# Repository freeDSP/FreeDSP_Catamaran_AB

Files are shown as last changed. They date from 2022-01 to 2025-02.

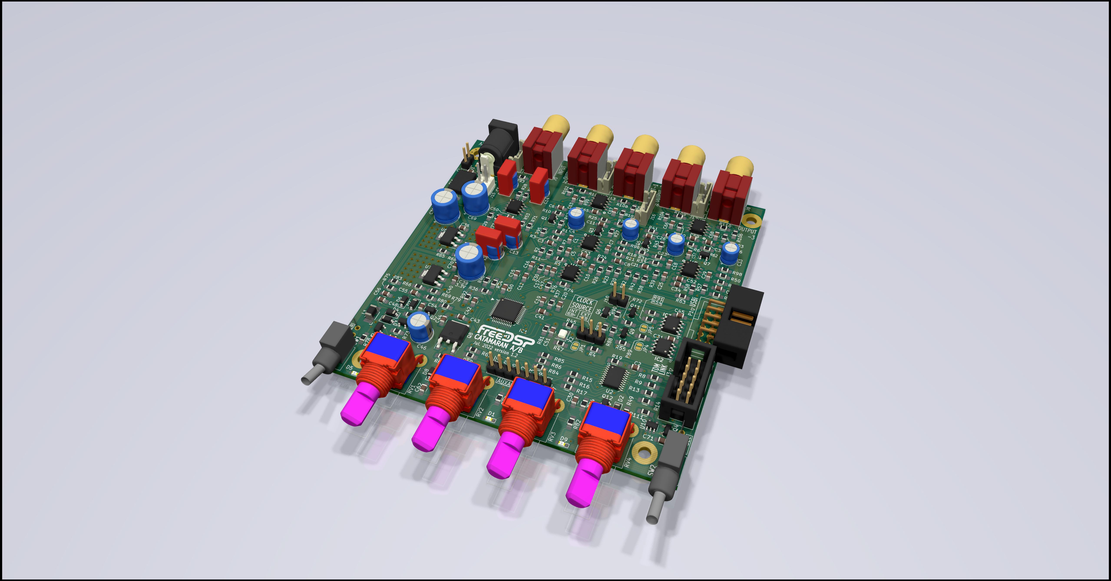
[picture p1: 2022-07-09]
Photo/FreeDSP_Catamaran_1v2_ParseRendering.jpg

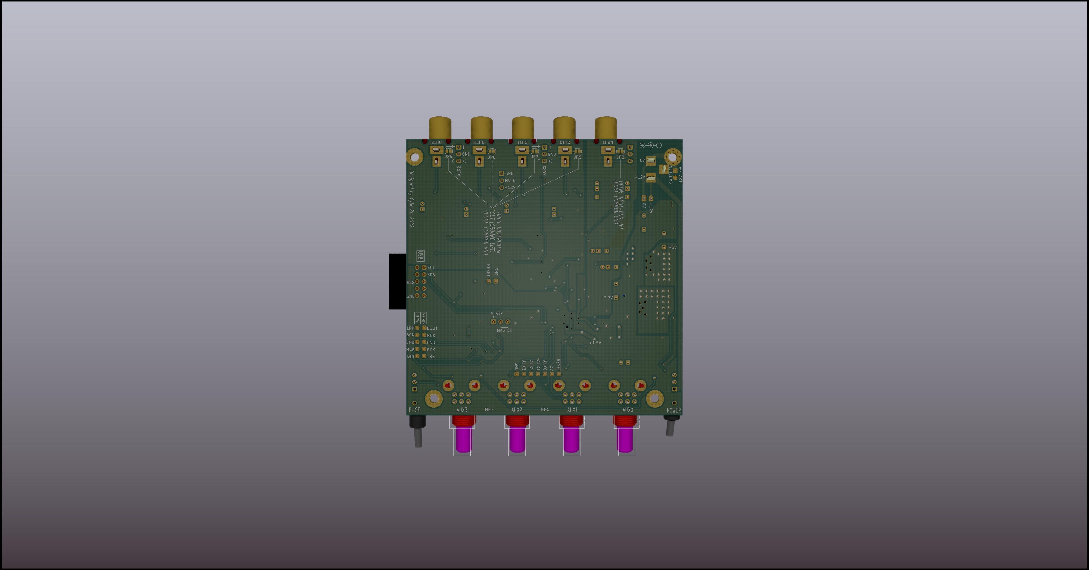
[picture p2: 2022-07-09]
Photo/FreeDSP_Catamaran_1v2_BottomRendering.jpg

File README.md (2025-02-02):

# FreeDSP_Catamaran_AB
A dual mono construction Concept Differential ADC 1 in 4 out ADAU1701 board. Extreme High performance (ADC to DAC Overall Distortion 0.00087%) differential A/D Conversion, differential RCA-pin Outputs, fs=96kHz, 8 slots TDM-Interlink across the boards.

Features:

- 1in 4 out RCA jacks on each PCB (2 boards requires for stereo use)
- High-performance differential monaural ADAU1701 ADC circuit
- GND lift-able Differntial RCA-pin Input curcuit
- GND lift-able Differential RCA-pin Output circuit
- Mains Power Switch
- Power-ON/OFF/Reboot Anti-Pop Audio Mute
- LED Power Indicator
- MP1/MP7 controlled LED Indicators
- A/B Program Select switch with Auto-Reboot feature
- Selectable DSP reboot Dual-EEPROMs
- Rotary Pots for AUXADC 0-3
- interlink header for AUXADC control voltage 0-3 and Reset
- Common-mode Choke filtered Power Supply Input
- 0805(2.0mm x 1.25mm) SMD Resistors & Capacitors
- Prepare for the through-hole Ele-Caps on the Audio Path
- Unity Gain Analog Audio Input and Output (2V RMS)
- Absolute Phase transparent. (No need to invert Output Phase)
- Buffered TDM Interlink I/O Header (with Enable control)
- JST-EH Connectors for Optional XLR output driver board.

PCBA file package included in JLPCB_OrderFiles. You can order SMT and Boards. (https://jlcpcb.com/) 

A Wiki Page(https://github.com/freeDSP/FreeDSP_Catamaran_AB/wiki) of this project

Discussion forum thread (https://www.diyaudio.com/community/threads/freedsp-catamaran-a-b.381417/)

Project web page: (Direct Link) https://cyberpithilo.web.fc2.com/audio/freedsp/index.html

Project web page: (Yandex Machine Translation) https://translate.yandex.com/translate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

Project web page: (Google Machine Translation) https://cyberpithilo-web-fc2-com.translate.goog/audio/freedsp/catamaran_main.html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

# License
This work and all other materials under https://github.com/freeDSP are licensed under a Creative Commons Attribution Share-Alike 4.0 license. This allows for both personal and commercial derivative works, as long as they credit freeDSP and release their designs under the same license.

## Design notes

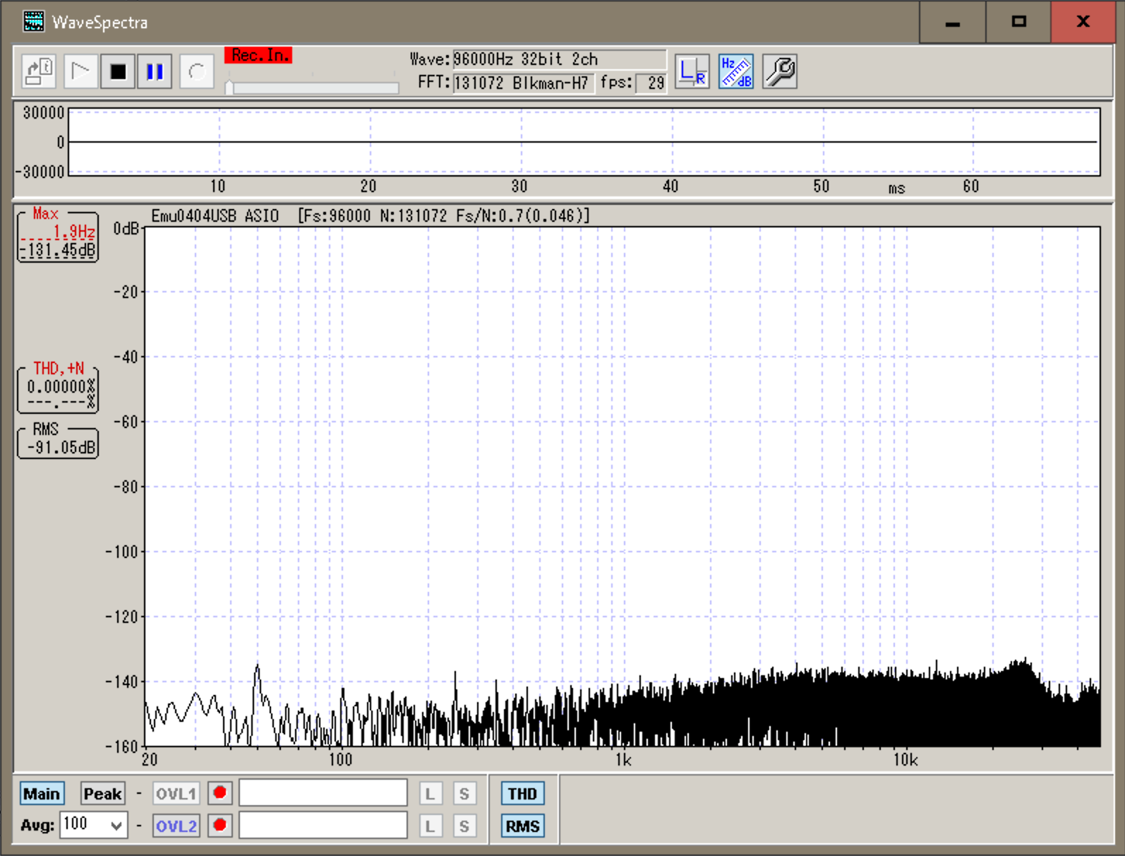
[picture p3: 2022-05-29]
Photo/RemainNoiseSPectrum.png

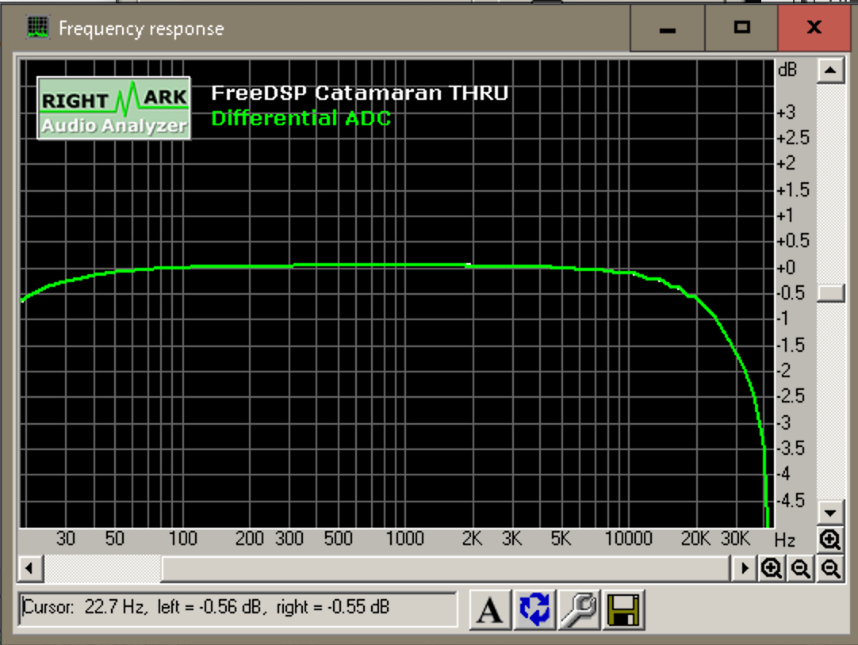
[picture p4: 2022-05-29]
Photo/Frequency Response(96kHz).png

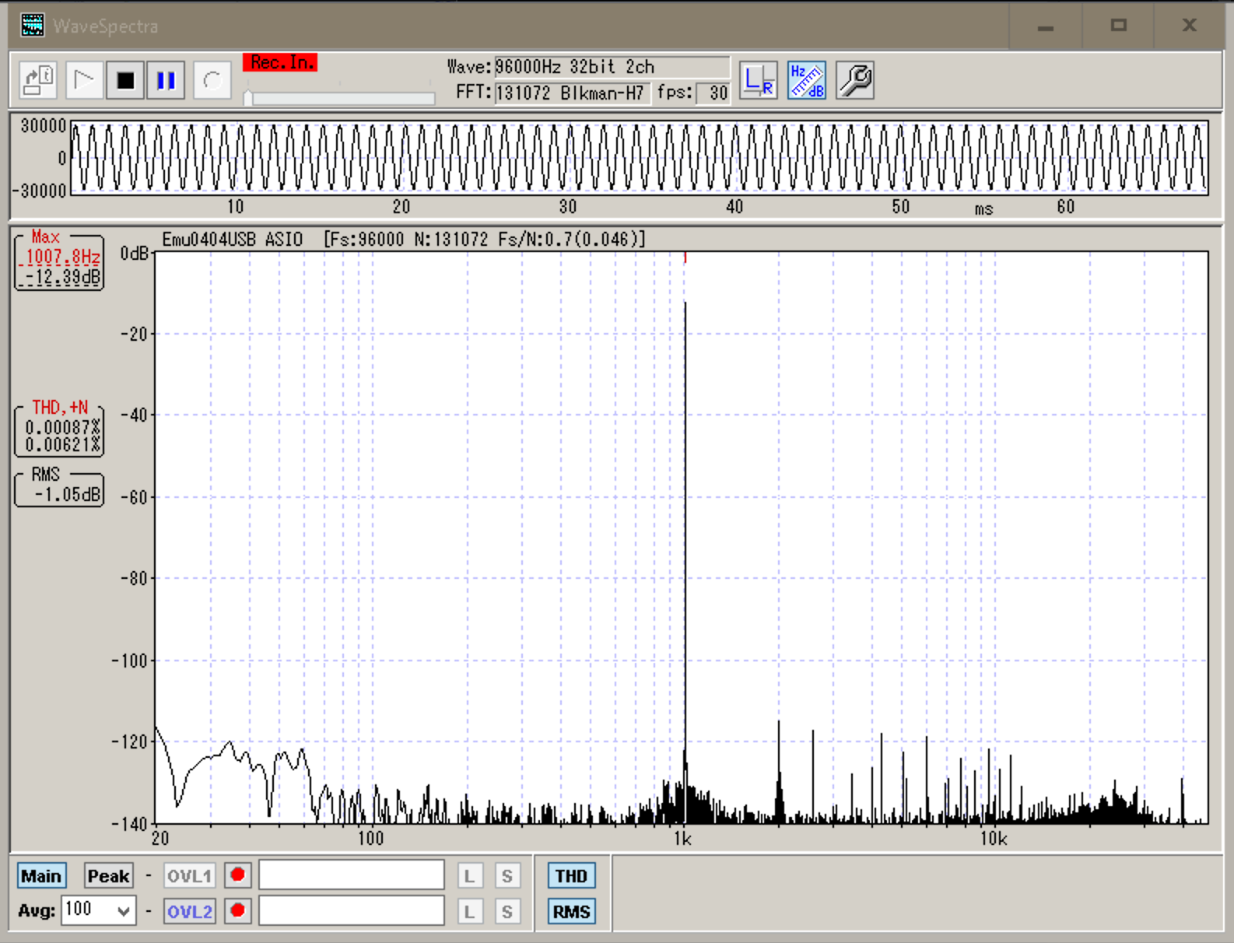
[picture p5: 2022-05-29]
Photo/0v21_Differential-ADC_THD.png

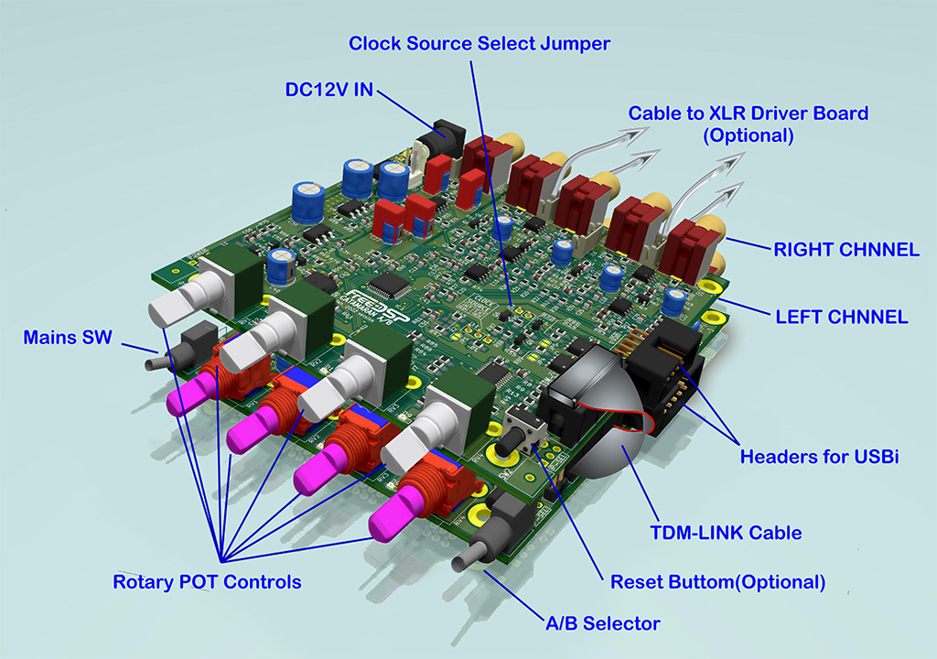
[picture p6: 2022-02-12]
Photo/FreeDSP_CatamaranStackedImage.jpg

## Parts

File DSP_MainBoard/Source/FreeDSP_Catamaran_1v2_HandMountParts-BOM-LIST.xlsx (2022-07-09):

Comment | Designator | Footprint | JLCPCB Part #（optional） | QTY for Stereo Link | COMMENT | SHOP URL
100u/16V | C46 | Capacitor_THT:CP_Radial_D6.3mm_P2.50mm |  | 2 | OS-CON | https://akizukidenshi.com/catalog/g/gP-08290/
10u/16V | C23 | Capacitor_THT:CP_Radial_D5.0mm_P2.00mm |  | 8 | Elecaps for Audio | https://akizukidenshi.com/catalog/g/gP-04621/
10u/16V | C33 | Capacitor_THT:CP_Radial_D5.0mm_P2.00mm
10u/16V | C4 | Capacitor_THT:CP_Radial_D5.0mm_P2.00mm
10u/16V | C9 | Capacitor_THT:CP_Radial_D5.0mm_P2.00mm
2.2uF/16 | C14 | Myfootprints:CP_Combo_D5.0mm_P2-5mm |  | 4 | Film or Elecaps for Audio
2.2uF/16 | C58 | Myfootprints:CP_Combo_D5.0mm_P2-5mm
220u | C38 | Capacitor_THT:CP_Radial_D8.0mm_P5.00mm |  | 6 | OS-CON | https://akizukidenshi.com/catalog/g/gP-08291/
220u | C39 | Capacitor_THT:CP_Radial_D8.0mm_P5.00mm
220u/16V | C69 | Capacitor_THT:CP_Radial_D8.0mm_P5.00mm
2MS1T1B4M7QES | SW1 | Myfootprints:2MS1T1B4M7QES |  | 3pcs Total or 2pcs for Linked | POWER SWITCH | https://akizukidenshi.com/catalog/g/gP-13796/
2MS1T1B4M7QES | SW2 | Myfootprints:2MS1T1B4M7QES |  |  | PROGRAM SELECT SWITCH | https://akizukidenshi.com/catalog/g/gP-13796/
47uF/6.3 | C13 | Myfootprints:CP_Combo_D5.0mm_P2-5mm |  | 4 | Elecaps for Audio
47uF/6.3 | C22 | Myfootprints:CP_Combo_D5.0mm_P2-5mm
ALPS_RK09_B10K | RV1 | Potentiometers:Potentiometer_Alps_RK09L_Double_Vertical |  | 4pcs Total or 8pcs | 4pcs if use J7 interlink 8pcs for separate control | https://akizukidenshi.com/catalog/g/gP-12576/
ALPS_RK09_B10K | RV2 | Potentiometers:Potentiometer_Alps_RK09L_Double_Vertical
ALPS_RK09_B10K | RV3 | Potentiometers:Potentiometer_Alps_RK09L_Double_Vertical
ALPS_RK09_B10K | RV4 | Potentiometers:Potentiometer_Alps_RK09L_Double_Vertical
B3B-EH | J12 | Connector_JST:JST_XH_B3B-XH-AM_1x03_P2.50mm_Vertical |  | Optional for XLR Board | Optional for input/output for XLR Connector Board | https://www.digikey.jp/ja/products/detail/jst-sales-america-inc/B3B-EH-A-LF-SN/926521
B3B-EH | J13 | Connector_JST:JST_XH_B3B-XH-AM_1x03_P2.50mm_Vertical
B3B-EH | J14 | Connector_JST:JST_XH_B3B-XH-AM_1x03_P2.50mm_Vertical
Conn_01x02 | J1 | Connector_PinHeader_2.54mm:PinHeader_1x02_P2.54mm_Vertical |  | Long Pin-Header & Socket for Stacking | Interlink for DC 12V Supply Power
Conn_01x02 | J10 | Connector_PinHeader_2.54mm:PinHeader_1x02_P2.54mm_Vertical |  |  | Interlink for synchroniced RESET
B3B-EH | J16 | Connector_PinHeader_2.54mm:PinHeader_1x03_P2.54mm_Vertical |  | JST EH BasePost | Optional for XLR Board Power & Reset
Conn_01x07_Male | J7 | Connector_PinHeader_2.54mm:PinHeader_1x07_P2.54mm_Vertical |  | Socket for Stacking | Optional for votage Interlink Potentiometer and Reset
Conn_02x5_Odd_Even | J3 | Connector_IDC:IDC-Header_2x05_P2.54mm_Vertical |  | 2 | Plus Reverse connected 10P IDC cable required for Stereo Link | https://akizukidenshi.com/catalog/g/gC-12664/
Conn_Power_2.1mm | J9 | Connect:BARREL_JACK |  | 1pce total | 5.5mm Sleeve 2.1mm Center-Pin
Conn_RCA | J2 | MyJacks:RJ-2410N |  | RED & WHITE 5pcs each | REDx5pcs and WHITEx5pcs | https://akizukidenshi.com/catalog/g/gC-16498/
Conn_RCA | J4 | MyJacks:RJ-2410N |  |  |  | https://akizukidenshi.com/catalog/g/gC-16497/
Conn_RCA | J5 | MyJacks:RJ-2410N |  |  |  | https://www.digikey.jp/ja/products/detail/kycon-inc/KLPX-0848A-2-R/9990119
Conn_RCA | J6 | MyJacks:RJ-2410N |  |  |  | https://www.digikey.jp/ja/products/detail/kycon-inc/KLPX-0848A-2-W/9990120
Conn_RCA | J8 | MyJacks:RJ-2410N
HeaderPin_01x03 | J11 | Connector_PinHeader_2.54mm:PinHeader_1x03_P2.54mm_Vertical |  | 2 | JUMPER-PIN Requred for each
MIL-10P_Angle | P1 | Connector_IDC:IDC-Header_2x05_P2.54mm_Right Angle |  | 2 | for USBi | https://akizukidenshi.com/catalog/g/gC-13178/
Molex 1718563002 | J15 | Connector_Molex:Molex_KK-254_AE-6410-02A_1x02_P2.54mm_Vertical |  | Optional | for external power supply
NOP | R59 | Resistors_SMD:R_0805_HandSoldering |  | 0 | Not need
24AA256(or CAT24M01WI-GT3) | IC2 | Housings_SOIC:SOIC-8_3.9x4.9mm_Pitch1.27mm |  | 2 | I2C EEPROM | https://akizukidenshi.com/catalog/g/gI-10492/
24AA256(or CAT24M01WI-GT3) | IC3 | Housings_SOIC:SOIC-8_3.9x4.9mm_Pitch1.27mm |  | 2 | I2C EEPROM | https://akizukidenshi.com/catalog/g/gI-10492/

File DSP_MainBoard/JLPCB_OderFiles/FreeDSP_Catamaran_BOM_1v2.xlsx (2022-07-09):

Comment | Designator | Footprint | JLCPCB Part #（optional）
0R | R68 | Resistors_SMD:R_0805_HandSoldering | C17477
0R | R69 | Resistors_SMD:R_0805_HandSoldering | C17477
0R | R76 | Resistors_SMD:R_0805_HandSoldering | C17477
0R | R80 | Resistors_SMD:R_0805_HandSoldering | C17477
0R | R92 | Resistors_SMD:R_0805_HandSoldering | C17477
1000PF | C21 | Capacitors_SMD:C_0805_HandSoldering | C343010
1000PF | C3 | Capacitors_SMD:C_0805_HandSoldering | C343010
1000PF | C32 | Capacitors_SMD:C_0805_HandSoldering | C343010
1000PF | C8 | Capacitors_SMD:C_0805_HandSoldering | C343010
100k | R67 | Resistors_SMD:R_0805_HandSoldering | C149504
100k | R74 | Resistors_SMD:R_0805_HandSoldering | C149504
100n | C17 | Capacitors_SMD:C_0805_HandSoldering | C49678
100n | C2 | Capacitors_SMD:C_0805_HandSoldering | C49678
100n | C24 | Capacitors_SMD:C_0805_HandSoldering | C49678
100n | C31 | Capacitors_SMD:C_0805_HandSoldering | C49678
100n | C37 | Capacitors_SMD:C_0805_HandSoldering | C49678
100n | C42 | Capacitors_SMD:C_0805_HandSoldering | C49678
100n | C44 | Capacitors_SMD:C_0805_HandSoldering | C49678
100n | C45 | Capacitors_SMD:C_0805_HandSoldering | C49678
100n | C50 | Capacitors_SMD:C_0805_HandSoldering | C49678
100n | C51 | Capacitors_SMD:C_0805_HandSoldering | C49678
100n | C52 | Capacitors_SMD:C_0805_HandSoldering | C49678
100n | C53 | Capacitors_SMD:C_0805_HandSoldering | C49678
100n | C59 | Capacitors_SMD:C_0805_HandSoldering | C49678
100n | C60 | Capacitors_SMD:C_0805_HandSoldering | C49678
100n | C61 | Capacitors_SMD:C_0805_HandSoldering | C49678
100n | C65 | Capacitors_SMD:C_0805_HandSoldering | C49678
100n | C70 | Capacitors_SMD:C_0805_HandSoldering | C49678
100n | C71 | Capacitors_SMD:C_0805_HandSoldering | C49678
100R | R13 | Resistors_SMD:R_0805_HandSoldering | C17408
100R | R14 | Resistors_SMD:R_0805_HandSoldering | C17408
100R | R15 | Resistors_SMD:R_0805_HandSoldering | C17408
100R | R16 | Resistors_SMD:R_0805_HandSoldering | C17408
100R | R17 | Resistors_SMD:R_0805_HandSoldering | C17408
100R | R4 | Resistors_SMD:R_0805_HandSoldering | C17408
100R | R45 | Resistors_SMD:R_0805_HandSoldering | C17408
100R | R8 | Resistors_SMD:R_0805_HandSoldering | C17408
100R | R81 | Resistors_SMD:R_0805_HandSoldering | C17408
100R | R84 | Resistors_SMD:R_0805_HandSoldering | C17408
100R | R85 | Resistors_SMD:R_0805_HandSoldering | C17408
100R | R86 | Resistors_SMD:R_0805_HandSoldering | C17408
100R | R9 | Resistors_SMD:R_0805_HandSoldering | C17408
100R | R93 | Resistors_SMD:R_0805_HandSoldering | C17408
10k | R100 | Resistors_SMD:R_0805_HandSoldering | C17414
10k | R101 | Resistors_SMD:R_0805_HandSoldering | C17414
10k | R102 | Resistors_SMD:R_0805_HandSoldering | C17414
10k | R103 | Resistors_SMD:R_0805_HandSoldering | C17414
10k | R104 | Resistors_SMD:R_0805_HandSoldering | C17414
10k | R105 | Resistors_SMD:R_0805_HandSoldering | C17414
10k | R106 | Resistors_SMD:R_0805_HandSoldering | C17414
10k | R19 | Resistors_SMD:R_0805_HandSoldering | C17414
10k | R2 | Resistors_SMD:R_0805_HandSoldering | C17414
10k | R20 | Resistors_SMD:R_0805_HandSoldering | C17414
10k | R23 | Resistors_SMD:R_0805_HandSoldering | C17414
10k | R28 | Resistors_SMD:R_0805_HandSoldering | C17414
10k | R30 | Resistors_SMD:R_0805_HandSoldering | C17414
10k | R32 | Resistors_SMD:R_0805_HandSoldering | C17414
10k | R38 | Resistors_SMD:R_0805_HandSoldering | C17414
10k | R40 | Resistors_SMD:R_0805_HandSoldering | C17414
10k | R47 | Resistors_SMD:R_0805_HandSoldering | C17414
10k | R51 | Resistors_SMD:R_0805_HandSoldering | C17414
10k | R55 | Resistors_SMD:R_0805_HandSoldering | C17414
10k | R57 | Resistors_SMD:R_0805_HandSoldering | C17414
10k | R6 | Resistors_SMD:R_0805_HandSoldering | C17414
10k | R61 | Resistors_SMD:R_0805_HandSoldering | C17414
10k | R72 | Resistors_SMD:R_0805_HandSoldering | C17414
10k | R83 | Resistors_SMD:R_0805_HandSoldering | C17414
10k | R90 | Resistors_SMD:R_0805_HandSoldering | C17414
10k | R99 | Resistors_SMD:R_0805_HandSoldering | C17414
10u | C12 | Capacitors_SMD:C_0805_HandSoldering | C15850
10u | C15 | Capacitors_SMD:C_0805_HandSoldering | C15850
10u | C16 | Capacitors_SMD:C_0805_HandSoldering | C15850
10u | C40 | Capacitors_SMD:C_0805_HandSoldering | C15850
10u | C43 | Capacitors_SMD:C_0805_HandSoldering | C15850
10u | C62 | Capacitors_SMD:C_0805_HandSoldering | C15850
10uF/25V | C27 | Capacitors_SMD:C_0805_HandSoldering | C15850
10uF/25V | C28 | Capacitors_SMD:C_0805_HandSoldering | C15850
10uF/25V | C36 | Capacitors_SMD:C_0805_HandSoldering | C15850
10uF/25V | C48 | Capacitors_SMD:C_0805_HandSoldering | C15850
10uF/25V | C57 | Capacitors_SMD:C_0805_HandSoldering | C15850
150p | C1 | Capacitors_SMD:C_0805_HandSoldering | C159769
150p | C10 | Capacitors_SMD:C_0805_HandSoldering | C159769
150p | C18 | Capacitors_SMD:C_0805_HandSoldering | C159769
150p | C25 | Capacitors_SMD:C_0805_HandSoldering | C159769
150p | C29 | Capacitors_SMD:C_0805_HandSoldering | C159769
150p | C34 | Capacitors_SMD:C_0805_HandSoldering | C159769
150p | C5 | Capacitors_SMD:C_0805_HandSoldering | C159769
150p | C63 | Capacitors_SMD:C_0805_HandSoldering | C159769
150p | C66 | Capacitors_SMD:C_0805_HandSoldering | C159769
150p | C67 | Capacitors_SMD:C_0805_HandSoldering | C159769
150p | C68 | Capacitors_SMD:C_0805_HandSoldering | C159769
150p | C7 | Capacitors_SMD:C_0805_HandSoldering | C159769
15k | R34 | Resistors_SMD:R_0805_HandSoldering | C17475
15k | R36 | Resistors_SMD:R_0805_HandSoldering | C17475
15k | R46 | Resistors_SMD:R_0805_HandSoldering | C17475
1k | R21 | Resistors_SMD:R_0805_HandSoldering | C17513
1k | R24 | Resistors_SMD:R_0805_HandSoldering | C17513
1k | R3 | Resistors_SMD:R_0805_HandSoldering | C17513
1k | R33 | Resistors_SMD:R_0805_HandSoldering | C17513
1k | R39 | Resistors_SMD:R_0805_HandSoldering | C17513
1k | R48 | Resistors_SMD:R_0805_HandSoldering | C17513
1k | R52 | Resistors_SMD:R_0805_HandSoldering | C17513
1k | R58 | Resistors_SMD:R_0805_HandSoldering | C17513
1k | R60 | Resistors_SMD:R_0805_HandSoldering | C17513
1k | R7 | Resistors_SMD:R_0805_HandSoldering | C17513
1k | R70 | Resistors_SMD:R_0805_HandSoldering | C17513
1k | R75 | Resistors_SMD:R_0805_HandSoldering | C17513
1k | R78 | Resistors_SMD:R_0805_HandSoldering | C17513
1k | R79 | Resistors_SMD:R_0805_HandSoldering | C17513
1k | R82 | Resistors_SMD:R_0805_HandSoldering | C17513
1k | R87 | Resistors_SMD:R_0805_HandSoldering | C17513
1k | R89 | Resistors_SMD:R_0805_HandSoldering | C17513
1k | R91 | Resistors_SMD:R_0805_HandSoldering | C17513
1MEG | R73 | Resistors_SMD:R_0805_HandSoldering | C17514
1MEG | R88 | Resistors_SMD:R_0805_HandSoldering | C17514
1MEG | R94 | Resistors_SMD:R_0805_HandSoldering | C17514
1MEG | R111 | Resistors_SMD:R_0805_HandSoldering | C17514
1N4148W | D2 | Diodes_SMD:D_SOD-123 | C81598
1N4148W | D3 | Diodes_SMD:D_SOD-123 | C81598
2.2u | C30 | Capacitors_SMD:C_0805_HandSoldering | C49217
2.2u | C41 | Capacitors_SMD:C_0805_HandSoldering | C49217
2.2u | C47 | Capacitors_SMD:C_0805_HandSoldering | C49217
2.2u | C49 | Capacitors_SMD:C_0805_HandSoldering | C49217
2.2u | C54 | Capacitors_SMD:C_0805_HandSoldering | C49217
2.2u | C55 | Capacitors_SMD:C_0805_HandSoldering | C49217
2.2u | C56 | Capacitors_SMD:C_0805_HandSoldering | C49217
20k | R29 | Resistors_SMD:R_0805_HandSoldering | C4328
20k | R71 | Resistors_SMD:R_0805_HandSoldering | C4328
22k | R1 | Resistors_SMD:R_0805_HandSoldering | C17560
22k | R11 | Resistors_SMD:R_0805_HandSoldering | C17560
22k | R12 | Resistors_SMD:R_0805_HandSoldering | C17560
22k | R18 | Resistors_SMD:R_0805_HandSoldering | C17560
22k | R26 | Resistors_SMD:R_0805_HandSoldering | C17560
22k | R27 | Resistors_SMD:R_0805_HandSoldering | C17560
22k | R31 | Resistors_SMD:R_0805_HandSoldering | C17560
22k | R42 | Resistors_SMD:R_0805_HandSoldering | C17560
22k | R43 | Resistors_SMD:R_0805_HandSoldering | C17560
22k | R50 | Resistors_SMD:R_0805_HandSoldering | C17560
22k | R63 | Resistors_SMD:R_0805_HandSoldering | C17560
22k | R64 | Resistors_SMD:R_0805_HandSoldering | C17560
22k | R95 | Resistors_SMD:R_0805_HandSoldering | C17560
22k | R96 | Resistors_SMD:R_0805_HandSoldering | C17560
22k | R97 | Resistors_SMD:R_0805_HandSoldering | C17560
22k | R98 | Resistors_SMD:R_0805_HandSoldering | C17560
24AA256(or CAT24M01WI-GT3) | IC2 | Housings_SOIC:SOIC-8_3.9x4.9mm_Pitch1.27mm | C152172
24AA256(or CAT24M01WI-GT3) | IC3 | Housings_SOIC:SOIC-8_3.9x4.9mm_Pitch1.27mm | C152172
2k2 | R54 | Resistors_SMD:R_0805_HandSoldering | C17520
2SC3326 | Q1 | TO_SOT_Packages_SMD:SOT-23 | C27829
2SC3326 | Q3 | TO_SOT_Packages_SMD:SOT-23 | C27829
2SC3326 | Q5 | TO_SOT_Packages_SMD:SOT-23 | C27829
2SC3326 | Q7 | TO_SOT_Packages_SMD:SOT-23 | C27829
33pF | C64 | Capacitors_SMD:C_0805_HandSoldering | C157687
3n3 | C11 | Capacitors_SMD:C_0805_HandSoldering | C129655
3n3 | C19 | Capacitors_SMD:C_0805_HandSoldering | C129655
3n3 | C26 | Capacitors_SMD:C_0805_HandSoldering | C129655
3n3 | C35 | Capacitors_SMD:C_0805_HandSoldering | C129655
3n3 | C6 | Capacitors_SMD:C_0805_HandSoldering | C129655
4.7k | R49 | Resistors_SMD:R_0805_HandSoldering | C17673
470R | R37 | Resistors_SMD:R_0805_HandSoldering | C17710
47k | R10 | Resistors_SMD:R_0805_HandSoldering | C17713
47k | R25 | Resistors_SMD:R_0805_HandSoldering | C17713
47k | R41 | Resistors_SMD:R_0805_HandSoldering | C17713
47k | R44 | Resistors_SMD:R_0805_HandSoldering | C17713
47k | R62 | Resistors_SMD:R_0805_HandSoldering | C17713
47R | R107 | Resistors_SMD:R_0805_HandSoldering | C17714
47R | R108 | Resistors_SMD:R_0805_HandSoldering | C17714
47R | R109 | Resistors_SMD:R_0805_HandSoldering | C17714
47R | R110 | Resistors_SMD:R_0805_HandSoldering | C17714
47R | R53 | Resistors_SMD:R_0805_HandSoldering | C17714
47R | R77 | Resistors_SMD:R_0805_HandSoldering | C17714
56n | C20 | Capacitors_SMD:C_0805_HandSoldering | C1753
680R | R22 | Resistors_SMD:R_0805_HandSoldering | C17798
680R | R35 | Resistors_SMD:R_0805_HandSoldering | C17798
680R | R5 | Resistors_SMD:R_0805_HandSoldering | C17798
680R | R56 | Resistors_SMD:R_0805_HandSoldering | C17798
ACM9070-701-2PL-TL01 | FL1 | MyLibrary:ACM9070-701-2PL-TL01 | C14594
ADAU1701 | IC1 | Housings_QFP:LQFP-48_7x7mm_Pitch0.5mm | C26394
AO3400A | Q11 | digikey-footprints:SOT-23-3 | C20917
AO3400A | Q13 | TO_SOT_Packages_SMD:SOT-23 | C20917
AO3400A | Q2 | TO_SOT_Packages_SMD:SOT-23 | C20917
AO3400A | Q9 | digikey-footprints:SOT-23-3 | C20917
AO3400A | Q4 | TO_SOT_Packages_SMD:SOT-23 | C20917
AO3401A | Q10 | TO_SOT_Packages_SMD:SOT-23 | C15127
AO3401A | Q12 | TO_SOT_Packages_SMD:SOT-23 | C15127
AO3401A | Q6 | TO_SOT_Packages_SMD:SOT-23 | C15127
AZ1117-3.3 | U7 | TO_SOT_Packages_SMD:SOT-223-3_TabPin2 | C6186
AZ1117-5.0 | U6 | TO_SOT_Packages_SMD:SOT-223-3_TabPin2 | C6187
CMI321609X100KT | L1 | Inductors:Inductor_1212 | C1051
KTA1040D-Y-RTF/P | Q8 | TO_SOT_Packages_SMD:TO-252-2 | C69791
LED_RED | D1 | LEDs:LED_0603_HandSoldering | C2286
LED_RED | D9 | LEDs:LED_0603_HandSoldering | C2286
LED_WHITE | D5 | LEDs:LED_0603_HandSoldering | C2290
OPA1611 | U1 | Myfootprints:SOIC127P600X175-8N | C70884
OPA1611 | U3 | Myfootprints:SOIC127P600X175-8N | C70884
OPA1611 | U5 | Myfootprints:SOIC127P600X175-8N | C70884
OPA1611 | U8 | Myfootprints:SOIC127P600X175-8N | C70884
OPA1632DR | U9 | Myfootprints:SOIC127P600X175-8N | C86715
OPA1652 | U4 | Myfootprints:SOIC127P600X175-8N | C30025
RB160M-30 | D4 | Diodes_SMD:D_SOD-123 | C8598
RB160M-30 | D6 | Diodes_SMD:D_SOD-123 | C8598
RB160M-30 | D7 | Diodes_SMD:D_SOD-123 | C8598
RB160M-30 | D8 | Diodes_SMD:D_SOD-123 | C8598
S3D12.288000B20F30T | X2 | Oscillator:Oscillator_SMD_Abracon_ASE-4Pin_3.2x2.5mm | C387351
SN74LV541APWR | U2 | digikey-footprints:TSSOP-20_W4.4mm | C406870
SN74LVC1G86DBVR | U10 | Package_TO_SOT_SMD:TSOT-23-5 | C402161

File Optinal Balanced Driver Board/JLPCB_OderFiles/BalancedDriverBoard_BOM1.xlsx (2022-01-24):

Comment | Designator | Footprint | JLCPCB Part #（optional）
OPA1632DR | U1 | Package_SO:SOIC-8_3.9x4.9mm_P1.27mm | C86715
OPA1632DR | U2 | Package_SO:SOIC-8_3.9x4.9mm_P1.27mm | C86715
OPA1632DR | U3 | Package_SO:SOIC-8_3.9x4.9mm_P1.27mm | C86715
OPA1632DR | U4 | Package_SO:SOIC-8_3.9x4.9mm_P1.27mm | C86715
OPA1611AIDR | U5 | Package_SO:SOIC-8_3.9x4.9mm_P1.27mm | C86723
2SC3326 | Q1 | TO_SOT_Packages_SMD:SOT-23 | C79973
2SC3326 | Q2 | TO_SOT_Packages_SMD:SOT-23 | C79973
2SC3326 | Q3 | TO_SOT_Packages_SMD:SOT-23 | C79973
2SC3326 | Q4 | TO_SOT_Packages_SMD:SOT-23 | C79973
2SC3326 | Q5 | TO_SOT_Packages_SMD:SOT-23 | C79973
2SC3326 | Q6 | TO_SOT_Packages_SMD:SOT-23 | C79973
2SC3326 | Q7 | TO_SOT_Packages_SMD:SOT-23 | C79973
2SC3326 | Q8 | TO_SOT_Packages_SMD:SOT-23 | C79973
100n | C13 | Capacitors_SMD:C_0805_HandSoldering | C49678
100n | C14 | Capacitors_SMD:C_0805_HandSoldering | C49678
100n | C15 | Capacitors_SMD:C_0805_HandSoldering | C49678
100n | C16 | Capacitors_SMD:C_0805_HandSoldering | C49678
0.1uF | C37 | Capacitors_SMD:C_0805_HandSoldering | C49678
0.1uF | C40 | Capacitors_SMD:C_0805_HandSoldering | C49678
0.1uF | C44 | Capacitors_SMD:C_0805_HandSoldering | C49678
20k | R10 | Resistors_SMD:R_0805_HandSoldering | C4328
20k | R12 | Resistors_SMD:R_0805_HandSoldering | C4328
20k | R14 | Resistors_SMD:R_0805_HandSoldering | C4328
20k | R16 | Resistors_SMD:R_0805_HandSoldering | C4328
1uF | C38 | Capacitors_SMD:C_0805_HandSoldering | C28323
LED_RED | D1 | LEDs:LED_0603_HandSoldering | C2286
LED_RED | D2 | LEDs:LED_0603_HandSoldering | C2286
LED_RED | D3 | LEDs:LED_0603_HandSoldering | C2286
100pF | C17 | Capacitors_SMD:C_0805_HandSoldering | C1790
100pF | C18 | Capacitors_SMD:C_0805_HandSoldering | C1790
100pF | C19 | Capacitors_SMD:C_0805_HandSoldering | C1790
100pF | C20 | Capacitors_SMD:C_0805_HandSoldering | C1790
100pF | C21 | Capacitors_SMD:C_0805_HandSoldering | C1790
100pF | C22 | Capacitors_SMD:C_0805_HandSoldering | C1790
100pF | C23 | Capacitors_SMD:C_0805_HandSoldering | C1790
100pF | C24 | Capacitors_SMD:C_0805_HandSoldering | C1790
100pF | C25 | Capacitors_SMD:C_0805_HandSoldering | C1790
100pF | C26 | Capacitors_SMD:C_0805_HandSoldering | C1790
100pF | C27 | Capacitors_SMD:C_0805_HandSoldering | C1790
100pF | C28 | Capacitors_SMD:C_0805_HandSoldering | C1790
680R | R33 | Resistors_SMD:R_0805_HandSoldering | C17798
680R | R34 | Resistors_SMD:R_0805_HandSoldering | C17798
680R | R35 | Resistors_SMD:R_0805_HandSoldering | C17798
680R | R36 | Resistors_SMD:R_0805_HandSoldering | C17798
680R | R37 | Resistors_SMD:R_0805_HandSoldering | C17798
680R | R38 | Resistors_SMD:R_0805_HandSoldering | C17798
680R | R39 | Resistors_SMD:R_0805_HandSoldering | C17798
680R | R40 | Resistors_SMD:R_0805_HandSoldering | C17798
620R | R17 | Resistors_SMD:R_0805_HandSoldering | C17782
620R | R18 | Resistors_SMD:R_0805_HandSoldering | C17782
620R | R19 | Resistors_SMD:R_0805_HandSoldering | C17782
620R | R20 | Resistors_SMD:R_0805_HandSoldering | C17782
620R | R21 | Resistors_SMD:R_0805_HandSoldering | C17782
620R | R22 | Resistors_SMD:R_0805_HandSoldering | C17782
620R | R23 | Resistors_SMD:R_0805_HandSoldering | C17782
620R | R24 | Resistors_SMD:R_0805_HandSoldering | C17782
47k | R41 | Resistors_SMD:R_0805_HandSoldering | C17713
47k | R42 | Resistors_SMD:R_0805_HandSoldering | C17713
47k | R43 | Resistors_SMD:R_0805_HandSoldering | C17713
47k | R44 | Resistors_SMD:R_0805_HandSoldering | C17713
47k | R45 | Resistors_SMD:R_0805_HandSoldering | C17713
47k | R46 | Resistors_SMD:R_0805_HandSoldering | C17713
47k | R47 | Resistors_SMD:R_0805_HandSoldering | C17713
47k | R48 | Resistors_SMD:R_0805_HandSoldering | C17713
47k | R50 | Resistors_SMD:R_0805_HandSoldering | C17713
47k | R51 | Resistors_SMD:R_0805_HandSoldering | C17713
4.7k | R9 | Resistors_SMD:R_0805_HandSoldering | C17673
4.7k | R11 | Resistors_SMD:R_0805_HandSoldering | C17673
4.7k | R13 | Resistors_SMD:R_0805_HandSoldering | C17673
4.7k | R15 | Resistors_SMD:R_0805_HandSoldering | C17673
22R | R52 | Resistors_SMD:R_0805_HandSoldering | C17561
22R | R53 | Resistors_SMD:R_0805_HandSoldering | C17561
22R | R54 | Resistors_SMD:R_0805_HandSoldering | C17561
22R | R55 | Resistors_SMD:R_0805_HandSoldering | C17561
22k | R25 | Resistors_SMD:R_0805_HandSoldering | C17560
22k | R26 | Resistors_SMD:R_0805_HandSoldering | C17560
22k | R27 | Resistors_SMD:R_0805_HandSoldering | C17560
22k | R28 | Resistors_SMD:R_0805_HandSoldering | C17560
22k | R29 | Resistors_SMD:R_0805_HandSoldering | C17560
22k | R30 | Resistors_SMD:R_0805_HandSoldering | C17560
22k | R31 | Resistors_SMD:R_0805_HandSoldering | C17560
22k | R32 | Resistors_SMD:R_0805_HandSoldering | C17560
1k | R49 | Resistors_SMD:R_0805_HandSoldering | C17513
10k | R1 | Resistors_SMD:R_0805_HandSoldering | C17414
10k | R2 | Resistors_SMD:R_0805_HandSoldering | C17414
10k | R3 | Resistors_SMD:R_0805_HandSoldering | C17414
10k | R4 | Resistors_SMD:R_0805_HandSoldering | C17414
10k | R5 | Resistors_SMD:R_0805_HandSoldering | C17414
10k | R6 | Resistors_SMD:R_0805_HandSoldering | C17414
10k | R7 | Resistors_SMD:R_0805_HandSoldering | C17414
10k | R8 | Resistors_SMD:R_0805_HandSoldering | C17414
10u/25V | C9 | Capacitors_SMD:C_0805_HandSoldering | C15850
10u/25V | C10 | Capacitors_SMD:C_0805_HandSoldering | C15850
10u/25V | C11 | Capacitors_SMD:C_0805_HandSoldering | C15850
10u/25V | C12 | Capacitors_SMD:C_0805_HandSoldering | C15850
10u/25V | C39 | Capacitors_SMD:C_0805_HandSoldering | C15850
10uF | C42 | Capacitors_SMD:C_0805_HandSoldering | C15850
2.2uF/16 | C1 | Myfootprints:CP_Combo_D5.0mm_P2-5mm
2.2uF/16 | C2 | Myfootprints:CP_Combo_D5.0mm_P2-5mm
2.2uF/16 | C3 | Myfootprints:CP_Combo_D5.0mm_P2-5mm
2.2uF/16 | C4 | Myfootprints:CP_Combo_D5.0mm_P2-5mm
2.2uF/16 | C5 | Myfootprints:CP_Combo_D5.0mm_P2-5mm
2.2uF/16 | C6 | Myfootprints:CP_Combo_D5.0mm_P2-5mm
2.2uF/16 | C7 | Myfootprints:CP_Combo_D5.0mm_P2-5mm
2.2uF/16 | C8 | Myfootprints:CP_Combo_D5.0mm_P2-5mm
10u/16V | C29 | Capacitor_THT:CP_Radial_D5.0mm_P2.00mm
10u/16V | C30 | Capacitor_THT:CP_Radial_D5.0mm_P2.00mm
10u/16V | C31 | Capacitor_THT:CP_Radial_D5.0mm_P2.00mm
10u/16V | C32 | Capacitor_THT:CP_Radial_D5.0mm_P2.00mm
10u/16V | C33 | Capacitor_THT:CP_Radial_D5.0mm_P2.00mm
10u/16V | C34 | Capacitor_THT:CP_Radial_D5.0mm_P2.00mm
10u/16V | C35 | Capacitor_THT:CP_Radial_D5.0mm_P2.00mm
10u/16V | C36 | Capacitor_THT:CP_Radial_D5.0mm_P2.00mm
330uF/16V | C41 | Capacitor_THT:CP_Radial_D10.0mm_P2.50mm_P5.00mm
330uF/16V | C43 | Capacitor_THT:CP_Radial_D10.0mm_P2.50mm_P5.00mm
B3B-EH | J1 | Connector_JST:JST_XH_B3B-XH-AM_1x03_P2.50mm_Vertical
B3B-EH | J2 | Connector_JST:JST_XH_B3B-XH-AM_1x03_P2.50mm_Vertical
PD3MRMS2 | J3 | Myfootprints:SWITCHCRAFT_PD3MRMS2
PD3MRMS2 | J4 | Myfootprints:SWITCHCRAFT_PD3MRMS2
PD3MRMS2 | J5 | Myfootprints:SWITCHCRAFT_PD3MRMS2
PD3MRMS2 | J6 | Myfootprints:SWITCHCRAFT_PD3MRMS2
Conn_01x03 | J7 | Connector_PinHeader_2.54mm:PinHeader_1x03_P2.54mm_Vertical
PinHeader_01x02 | J8 | Connector_PinHeader_2.54mm:PinHeader_1x02_P2.54mm_Vertical
PinHeader_01x02 | J9 | Connector_PinHeader_2.54mm:PinHeader_1x02_P2.54mm_Vertical
PinHeader_01x02 | J10 | Connector_PinHeader_2.54mm:PinHeader_1x02_P2.54mm_Vertical
PinHeader_01x02 | J11 | Connector_PinHeader_2.54mm:PinHeader_1x02_P2.54mm_Vertical

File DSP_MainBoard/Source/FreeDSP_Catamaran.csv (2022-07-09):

Id | Designator | Package | Quantity | Designation | Supplier and ref
1 | G*** | FreeDSP_SmalW18 | 1 | LOGO
2 | JP2,JP6,JP7,JP8,JP9 | SolderJumper-2_P1.3mm_Open_RoundedPad1.0x1.5mm | 5 | Jumper_GLIFT
3 | RV4,RV2,RV1,RV3 | Potentiometer_Alps_RK09L_Double_Vertical | 4 | ALPS_RK09_B10K
4 | J14,J12,J13 | JST_XH_B3B-XH-AM_1x03_P2.50mm_Vertical | 3 | B3B-XH
5 | C13,C22 | CP_Combo_D5.0mm_P2-5mm | 2 | 47uF/6.3
6 | R98,R1,R11,R12,R18,R26,R27,R31,R42,R43,R50,R63,R64,R95,R96,R97 | R_0805_HandSoldering | 16 | 22k
7 | R94,R73,R88,R111 | R_0805_HandSoldering | 4 | 1MEG
8 | REF** | Symbol_Barrel_Polarity | 1 | Symbol_Barrel_Polarity
9 | R38,R2,R6,R19,R20,R23,R28,R30,R32,R40,R47,R51,R55,R57,R61,R72,R83,R90,R99,R100,R101,R102,R103,R104,R105,R106 | R_0805_HandSoldering | 26 | 10k
10 | C1,C5,C7,C10,C18,C25,C29,C34,C63,C66,C67,C68 | C_0805_HandSoldering | 12 | 150p
11 | C2,C17,C24,C31,C37,C42,C44,C45,C50,C51,C52,C53,C60,C61,C59,C65,C70,C71 | C_0805_HandSoldering | 18 | 100n
12 | C3,C8,C21,C32 | C_0805_HandSoldering | 4 | 1000PF
13 | C4,C9,C23,C33 | CP_Radial_D5.0mm_P2.00mm | 4 | 10u/16V
14 | C6,C11,C19,C26,C35 | C_0805_HandSoldering | 5 | 3n3
15 | C12,C15,C16,C40,C43,C62 | C_0805_HandSoldering | 6 | 10u
16 | C20 | C_0805_HandSoldering | 1 | 56n
17 | C30,C41,C47,C49,C54,C55,C56 | C_0805_HandSoldering | 7 | 2.2u
18 | C36,C27,C28,C57,C48 | C_0805_HandSoldering | 5 | 10uF/25V
19 | C38,C39 | CP_Radial_D8.0mm_P5.00mm | 2 | 220u
20 | C64 | C_0805_HandSoldering | 1 | 33pF
21 | D2,D3 | D_SOD-123 | 2 | 1N4148W
22 | D4,D6,D7,D8 | D_SOD-123 | 4 | RB160M-30
23 | D5 | LED_0603_HandSoldering | 1 | LED_WHITE
24 | FL1 | ACM9070-701-2PL-TL01 | 1 | ACM9070-701-2PL-TL01
25 | IC1 | LQFP-48_7x7mm_Pitch0.5mm | 1 | ADAU1701
26 | IC2,IC3 | SOIC-8_3.9x4.9mm_Pitch1.27mm | 2 | 24AA256
27 | J1,J10 | PinHeader_1x02_P2.54mm_Vertical | 2 | Conn_01x02
28 | J2,J4,J5,J6,J8 | RJ-2410N | 5 | Conn_RCA
29 | J3 | IDC-Header_2x05_P2.54mm_Vertical | 1 | Conn_02x5_Odd_Even
30 | J9 | BARREL_JACK | 1 | Conn_Power_2.1mm
31 | J11 | PinHeader_1x03_P2.54mm_Vertical | 1 | HeaderPin_01x03
32 | JP1,JP4,JP5 | SolderJumper-2_P1.3mm_Open_RoundedPad1.0x1.5mm | 3 | Jumper_WP
33 | MH1 | MountingHole_3.2mm_M3_Pad_Via | 1 | MountingHole_Pad
34 | Q1,Q3,Q5,Q7 | SOT-23 | 4 | 2SC3326
35 | Q2,Q13 | SOT-23 | 2 | AO3400A
36 | Q6,Q10,Q12 | SOT-23 | 3 | AO3401A
37 | Q8 | TO-252-2 | 1 | KTA1040D-Y-RTF/P
38 | Q9,Q11,Q4 | SOT-23-3 | 3 | AO3400A
39 | R3,R7,R21,R24,R33,R39,R52,R58,R60,R70,R75,R78,R79,R87,R89,R91,R48,R82 | R_0805_HandSoldering | 18 | 1k
40 | R4,R8,R9,R13,R14,R15,R16,R17,R45,R81,R84,R85,R86,R93 | R_0805_HandSoldering | 14 | 100R
41 | R5,R22,R35,R56,R68 | R_0805_HandSoldering | 5 | 680R
42 | R10,R25,R41,R44,R62 | R_0805_HandSoldering | 5 | 47k
43 | R29,R71 | R_0805_HandSoldering | 2 | 20k
44 | R34,R36,R46 | R_0805_HandSoldering | 3 | 15k
45 | R37 | R_0805_HandSoldering | 1 | 470R
46 | R49 | R_0805_HandSoldering | 1 | 4.7k
47 | R53,R77,R107,R108,R109,R110 | R_0805_HandSoldering | 6 | 47R
48 | R54 | R_0805_HandSoldering | 1 | 2k2
49 | R59 | R_0805_HandSoldering | 1 | NOP
50 | R65,R66 | R_0805_HandSoldering | 2 | 220R
51 | R67,R74 | R_0805_HandSoldering | 2 | 100k
52 | R69 | R_0805_HandSoldering | 1 | 360R
53 | R76,R80,R92 | R_0805_HandSoldering | 3 | 0R
54 | SW1,SW2 | 2MS1T1B4M7QES | 2 | 2MS1T1B4M7QES
55 | U1,U5,U3,U8 | SOIC127P600X175-8N | 4 | OPA1611
56 | U2 | TSSOP-20_W4.4mm | 1 | SN74LV541APWR
57 | U4 | SOIC127P600X175-8N | 1 | OPA1652
58 | U6,U7 | SOT-223-3_TabPin2 | 2 | AZ1117-ADJ
59 | X2 | Oscillator_SMD_Abracon_ASE-4Pin_3.2x2.5mm | 1 | 3N12288G33YC
60 | P1 | IDC-Header_2x05_P2.54mm_Vertical | 1 | MIL-10P_Angle
61 | D1,D9 | LED_0603_HandSoldering | 2 | LED_RED
62 | H2,H3,H4 | MountingHole_3.2mm_M3_Pad | 3 | MountingHole
63 | U9 | SOIC127P600X175-8N | 1 | OPA1632DR
64 | C46 | CP_Radial_D6.3mm_P2.50mm | 1 | 100u/16V
65 | C14,C58 | CP_Combo_D5.0mm_P2-5mm | 2 | 2.2uF/16
66 | J15 | Molex_KK-254_AE-6410-02A_1x02_P2.54mm_Vertical | 1 | Molex 1718563002
67 | J16 | PinHeader_1x03_P2.54mm_Vertical | 1 | Conn_01x03
68 | C69 | CP_Radial_D8.0mm_P5.00mm | 1 | 220u/16V
69 | L1 | Inductor_1212 | 1 | CMI321609X100KT
70 | J7 | PinHeader_1x07_P2.54mm_Vertical | 1 | Conn_01x07_Male
71 | U10 | TSOT-23-5 | 1 | SN74LVC1G86DBVR

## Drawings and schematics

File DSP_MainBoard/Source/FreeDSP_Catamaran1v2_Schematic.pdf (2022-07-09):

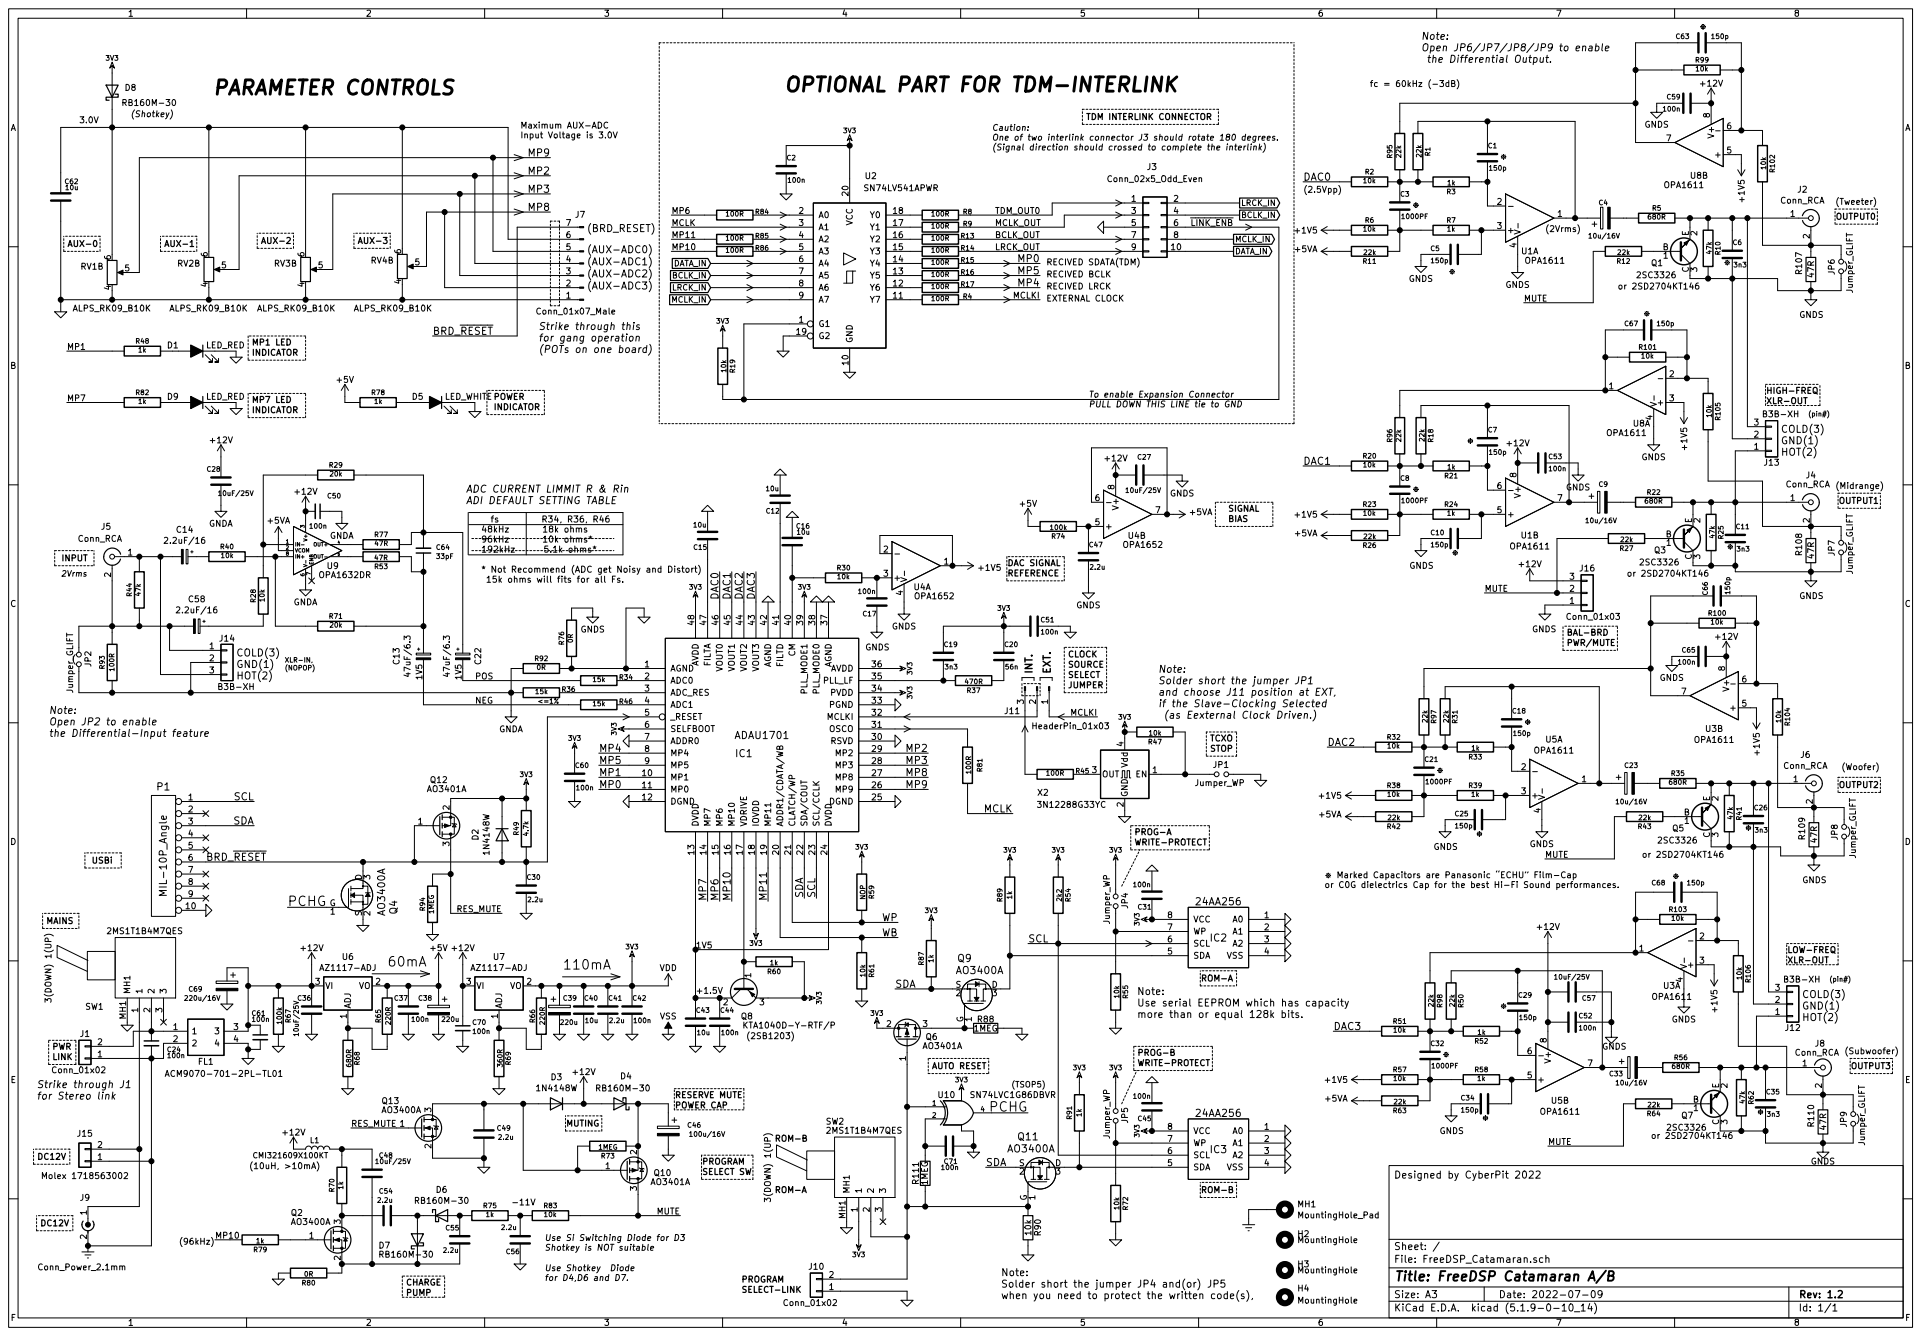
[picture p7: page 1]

PROG-B WRITE-PROTECT OPTIONAL PART FOR TDM-INTERLINK

Note: Open JP6/JP7/JP8/JP9 to enable

Caution: One of two interlink connector J3 should rotate 180 degrees.

(Signal direction should crossed to complete the interlink)

RECIVED SDATA(TDM)PROG-A WRITE-PROTECT

(AUX-ADC1) Note: Open JP2 to enable

Strike through this
for gang operation
(POTs on one board)

To enable Expansion Connector PULL DOWN THIS LINE tie to GND

HOT(2) Note: Solder short the jumper JP1

15k ohms will fits for all Fs. ADC CURRENT LIMMIT R & Rin ADI DEFAULT SETTING TABLE

or C0G dielectrics Cap for the best Hi-Fi Sound performances. BAL-BRD

and choose J11 position at EXT,
if the Slave-Clocking Selected
(as Eexternal Clock Driven.)

the Differential-Input feature

Marked Capacitors are Panasonic ECHU Film-Cap

more than or equal 128k bits. ROM-A

File: FreeDSP_Catamaran.sch Sheet: / Designed by CyberPit 2022

Use Si Switching Diode for D3
Shotkey is NOT suitable

Id: 1/1 Title: FreeDSP Catamaran A/B

when you need to protect the written code(s),

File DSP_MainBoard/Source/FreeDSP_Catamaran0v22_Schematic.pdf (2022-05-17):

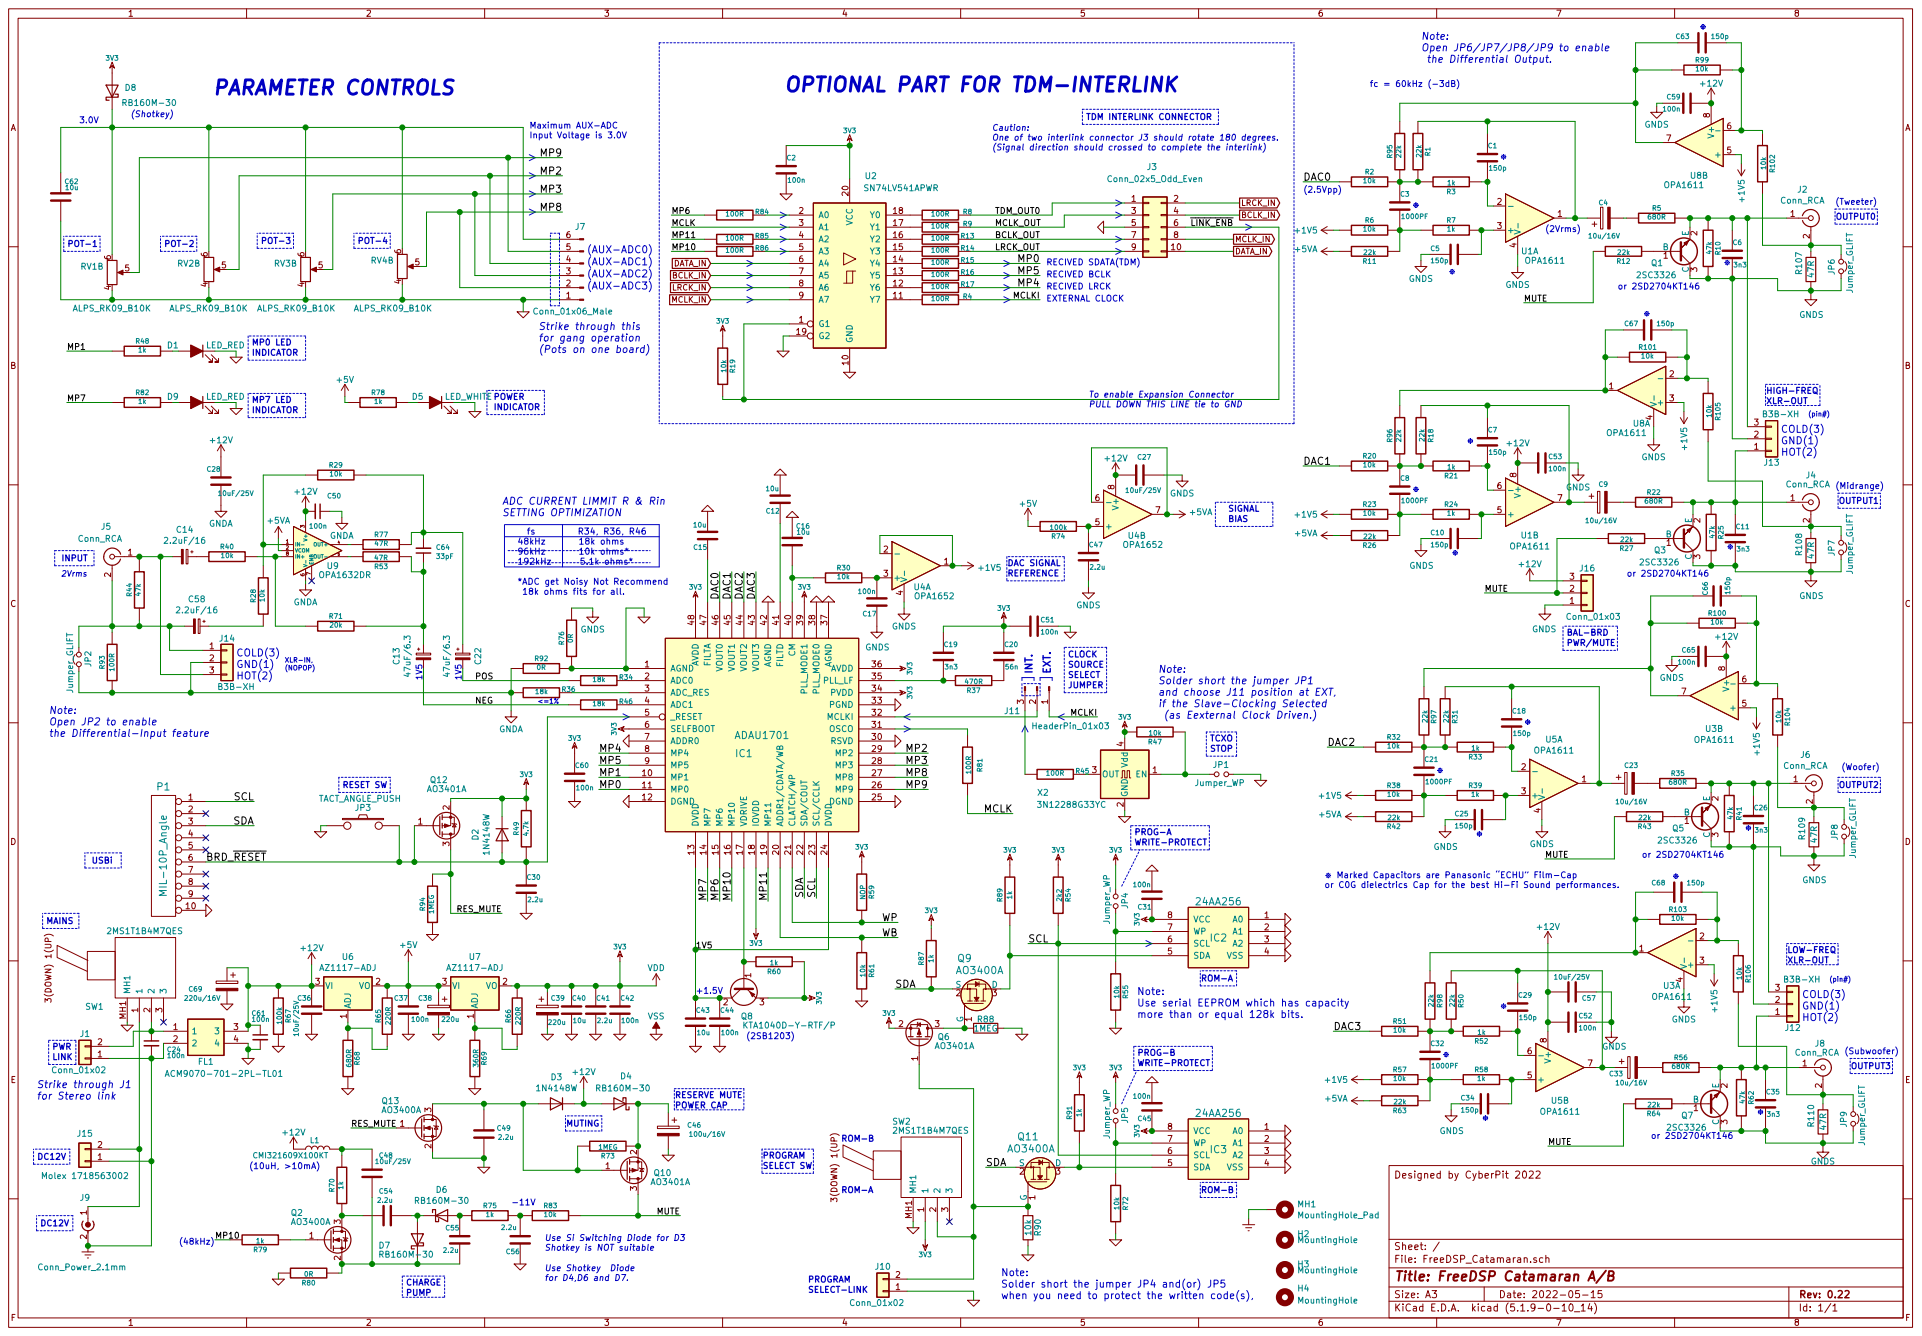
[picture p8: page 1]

PROG-B WRITE-PROTECT OPTIONAL PART FOR TDM-INTERLINK 1V5

fc = 60kHz (-3dB) RECIVED LRCK MAINS

(Signal direction should crossed to complete the interlink)

Strike through this
for gang operation
(Pots on one board)

HOT(2) Note: Solder short the jumper JP1

XLR-IN, (NOPOP) COLD(3)

and choose J11 position at EXT,
if the Slave-Clocking Selected
(as Eexternal Clock Driven.)

ROM-B Note: Open JP2 to enable

the Differential-Input feature

Marked Capacitors are Panasonic ECHU Film-Cap
or C0G dielectrics Cap for the best Hi-Fi Sound performances.

more than or equal 128k bits.

File: FreeDSP_Catamaran.sch Sheet: / Designed by CyberPit 2022

Use Si Switching Diode for D3

Note: Solder short the jumper JP4 and(or) JP5

Id: 1/1 Title: FreeDSP Catamaran A/B

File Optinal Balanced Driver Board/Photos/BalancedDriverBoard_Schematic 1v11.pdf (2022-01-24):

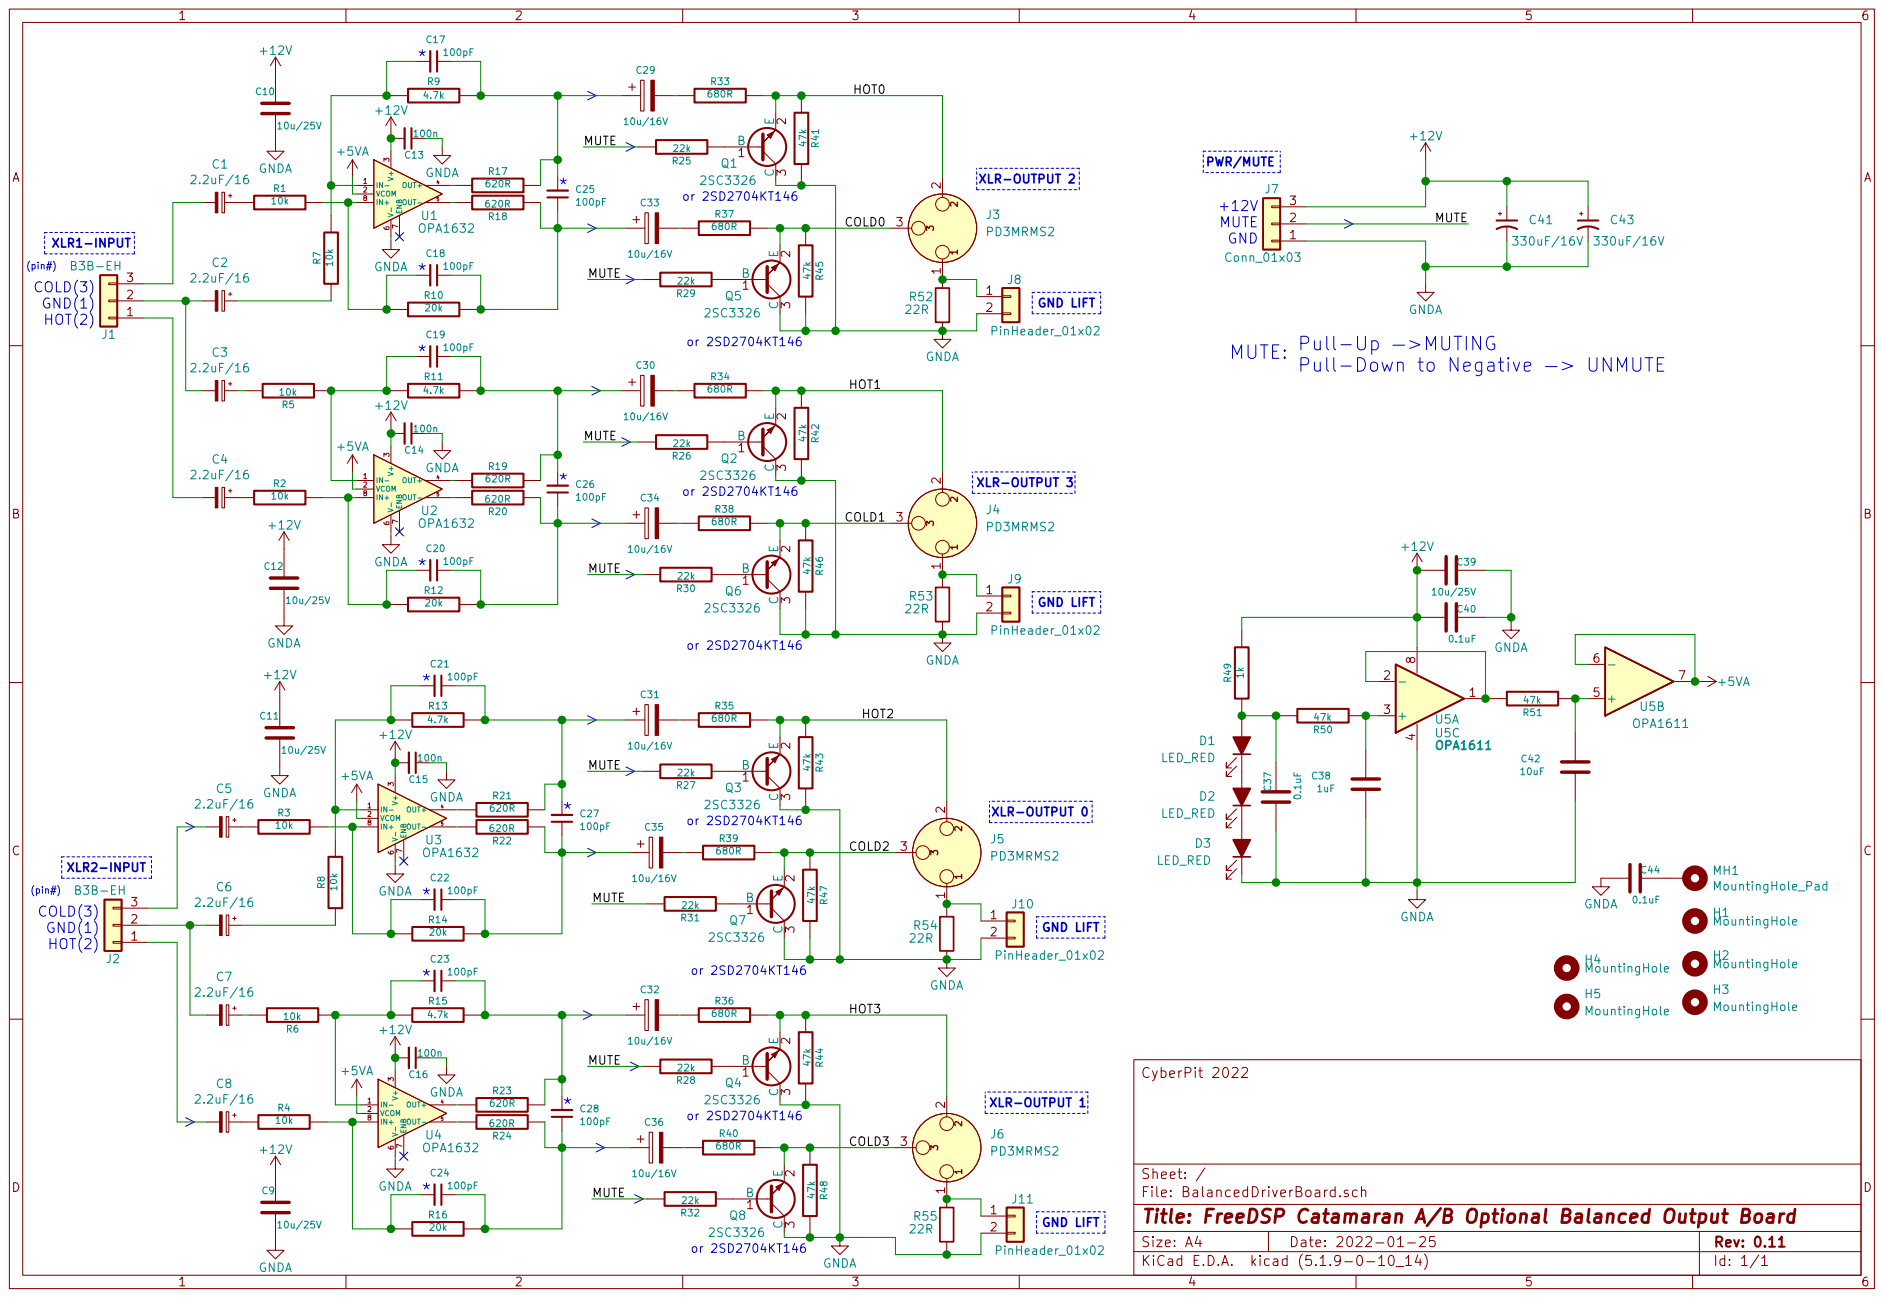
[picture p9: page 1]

Pull-Down to Negative > UNMUTE

File: BalancedDriverBoard.sch Sheet: / CyberPit 2022

Id: 1/1 Title: FreeDSP Catamaran A/B Optional Balanced Output Board

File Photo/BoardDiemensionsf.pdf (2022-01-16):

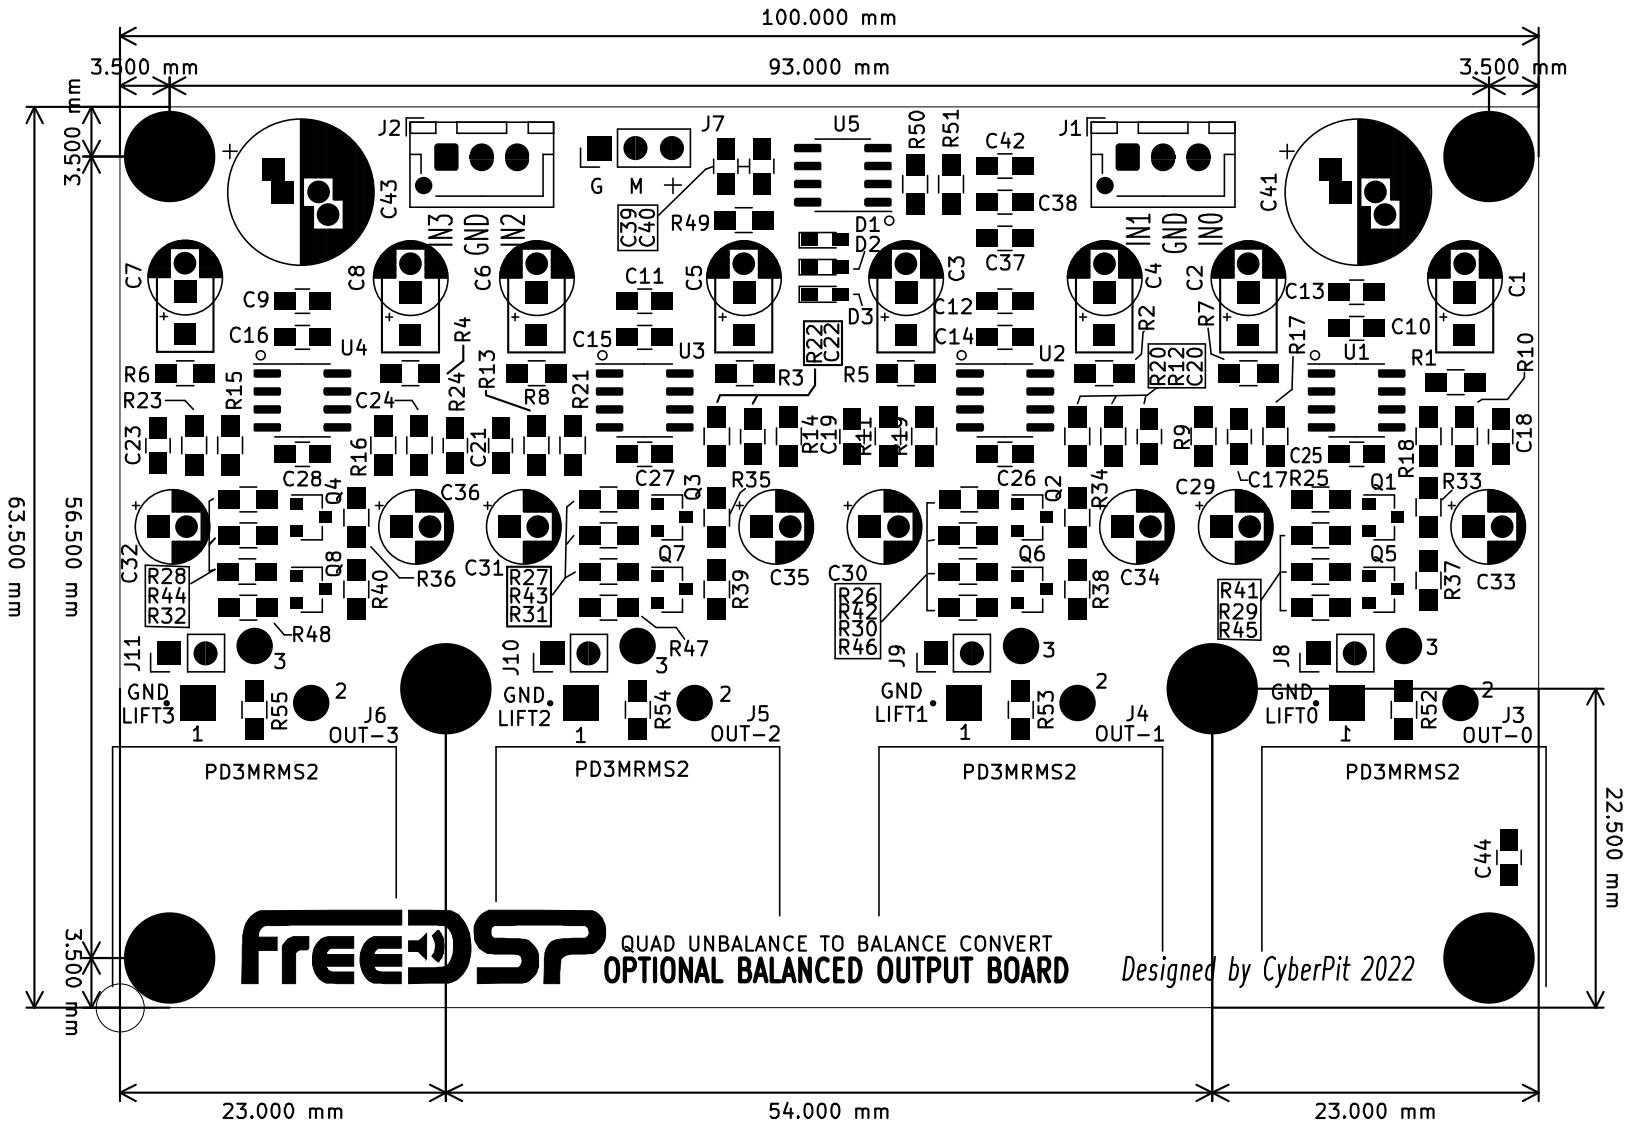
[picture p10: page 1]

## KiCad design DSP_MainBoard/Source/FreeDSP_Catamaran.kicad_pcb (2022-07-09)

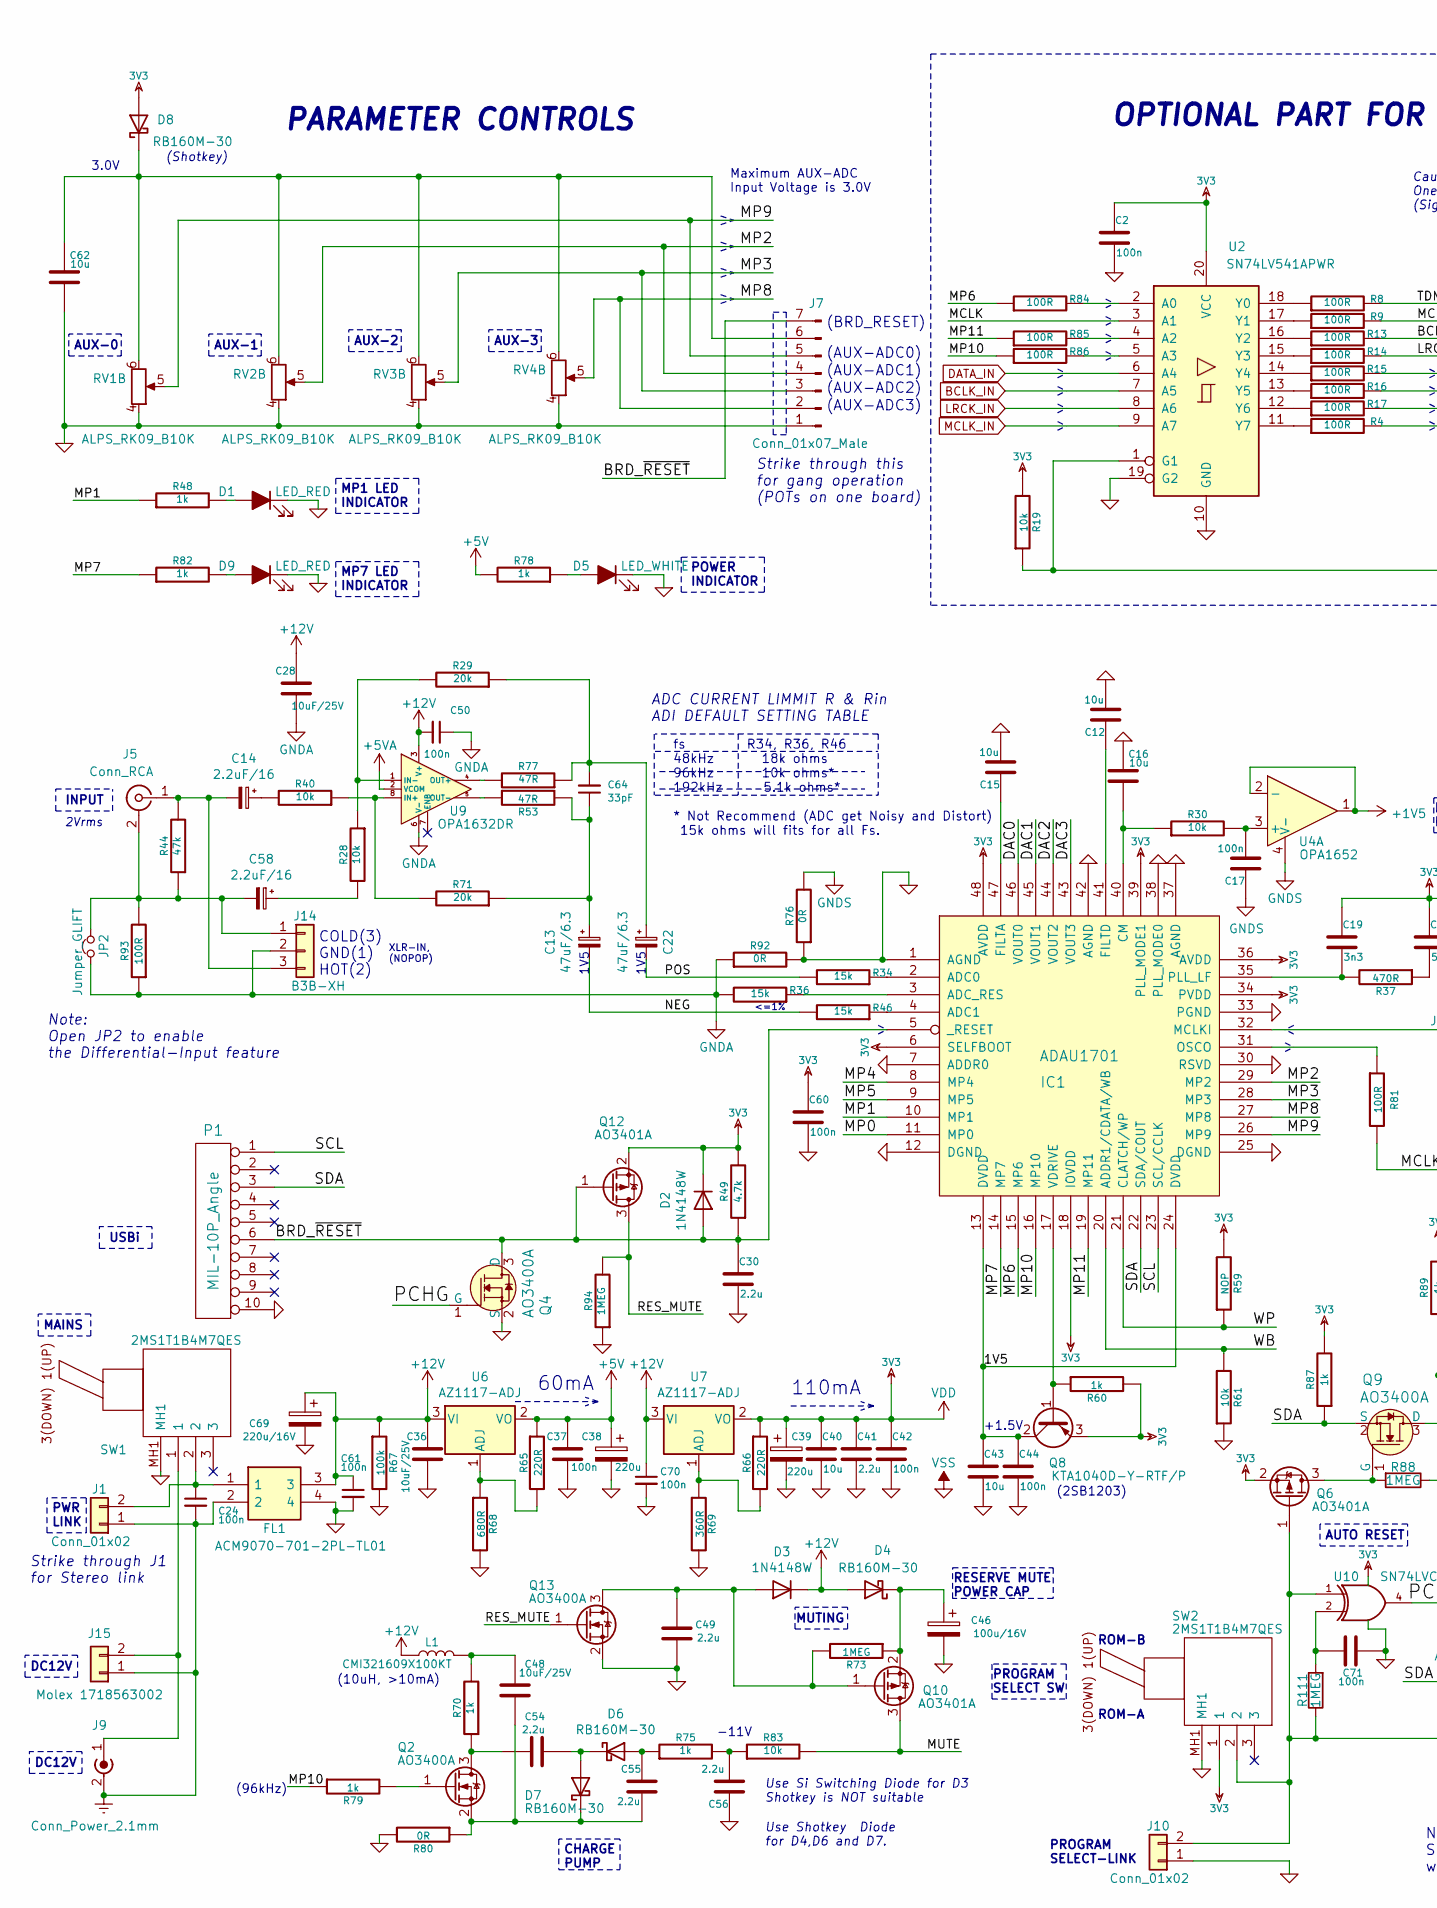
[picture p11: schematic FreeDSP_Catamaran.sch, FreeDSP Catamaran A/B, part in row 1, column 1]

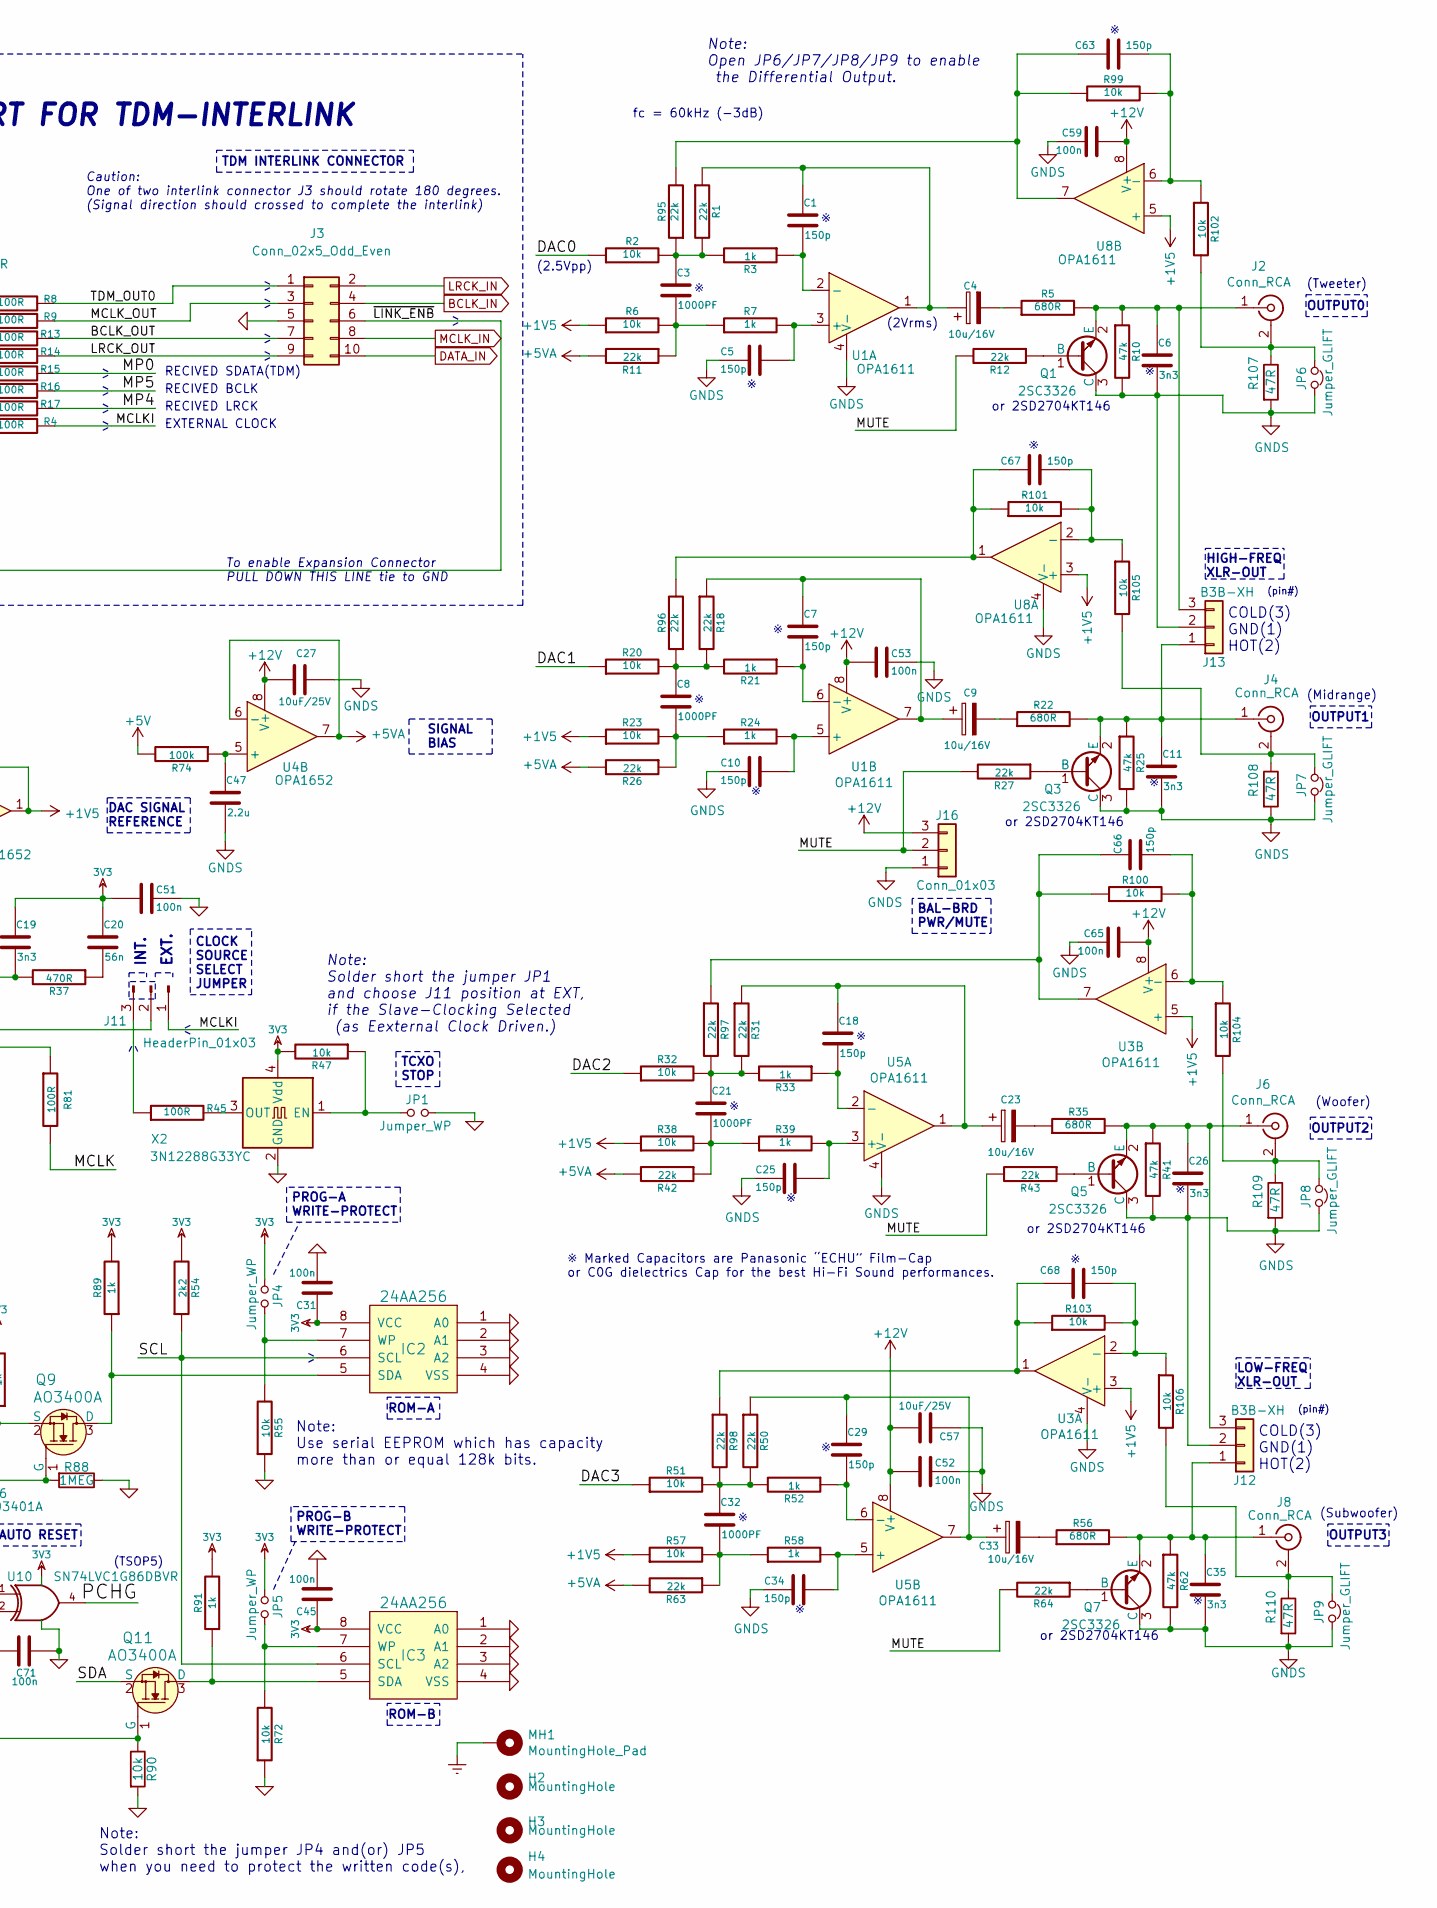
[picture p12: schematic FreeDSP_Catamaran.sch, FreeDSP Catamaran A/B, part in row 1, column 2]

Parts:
C1, C5, C7, C10, C18, C25, C29, C34, C63, C66, C67, C68: 150p; C_0805_HandSoldering
C2, C17, C24, C31, C37, C42, C44, C45, C50, C51, C52, C53, C59, C60, C61, C65, C70, C71: 100n; C_0805_HandSoldering
C3, C8, C21, C32: 1000PF; C_0805_HandSoldering
C4, C9, C23, C33: 10u/16V; CP_Radial_D5.0mm_P2.00mm
C6, C11, C19, C26, C35: 3n3; C_0805_HandSoldering
C12, C15, C16, C40, C43, C62: 10u; C_0805_HandSoldering
C13, C22: 47uF/6.3; CP_Combo_D5.0mm_P2-5mm
C14, C58: 2.2uF/16; CP_Combo_D5.0mm_P2-5mm
C20: 56n; C_0805_HandSoldering
C27, C28, C36, C48, C57: 10uF/25V; C_0805_HandSoldering
C30, C41, C47, C49, C54, C55, C56: 2.2u; C_0805_HandSoldering
C38, C39: 220u; CP_Radial_D8.0mm_P5.00mm
C46: 100u/16V; CP_Radial_D6.3mm_P2.50mm
C64: 33pF; C_0805_HandSoldering
C69: 220u/16V; CP_Radial_D8.0mm_P5.00mm
D1, D9: LED_RED; LED_0603_HandSoldering
D2, D3: 1N4148W; D_SOD-123
D4, D6, D7, D8: RB160M-30; D_SOD-123
D5: LED_WHITE; LED_0603_HandSoldering
FL1: ACM9070-701-2PL-TL01; Manufacturer_Part_Number ACM9070-701-2PL-TL01
H2, H3, H4: MountingHole; MountingHole_3.2mm_M3_Pad
IC1: ADAU1701; LQFP-48_7x7mm_Pitch0.5mm
IC2, IC3: 24AA256; SOIC-8_3.9x4.9mm_Pitch1.27mm
J1, J10: Conn_01x02; PinHeader_1x02_P2.54mm_Vertical
J2, J4, J5, J6, J8: Conn_RCA; RJ-2410N
J3: Conn_02x5_Odd_Even; IDC-Header_2x05_P2.54mm_Vertical
J7: Conn_01x07_Male; PinHeader_1x07_P2.54mm_Vertical
J9: Conn_Power_2.1mm; BARREL_JACK
J11: HeaderPin_01x03; PinHeader_1x03_P2.54mm_Vertical
J12, J13, J14: B3B-XH; JST_XH_B3B-XH-AM_1x03_P2.50mm_Vertical
J15: Molex 1718563002; Molex_KK-254_AE-6410-02A_1x02_P2.54mm_Vertical
J16: Conn_01x03; PinHeader_1x03_P2.54mm_Vertical
JP1, JP4, JP5: Jumper_WP; SolderJumper-2_P1.3mm_Open_RoundedPad1.0x1.5mm
JP2, JP6, JP7, JP8, JP9: Jumper_GLIFT; SolderJumper-2_P1.3mm_Open_RoundedPad1.0x1.5mm
L1: CMI321609X100KT; Inductor_1212; MPN LQH2MCN100K02L
MH1: MountingHole_Pad; MountingHole_3.2mm_M3_Pad_Via
P1: MIL-10P_Angle; IDC-Header_2x05_P2.54mm_Vertical
Q1, Q3, Q5, Q7: 2SC3326; SOT-23
Q2, Q13: AO3400A; SOT-23
Q4, Q9, Q11: AO3400A; SOT-23-3; MPN 2N7002; Digi-Key_PN 2N7002NCT-ND
Q6, Q10, Q12: AO3401A; SOT-23
Q8: KTA1040D-Y-RTF/P; TO-252-2
R1, R11, R12, R18, R26, R27, R31, R42, R43, R50, R63, R64, R95, R96, R97, R98: 22k; R_0805_HandSoldering
R2, R6, R19, R20, R23, R28, R30, R32, R38, R40, R47, R51, R55, R57, R61, R72, R83, R90, R99, R100, R101, R102, R103, R104, R105, R106: 10k; R_0805_HandSoldering
R3, R7, R21, R24, R33, R39, R48, R52, R58, R60, R70, R75, R78, R79, R82, R87, R89, R91: 1k; R_0805_HandSoldering
R4, R8, R9, R13, R14, R15, R16, R17, R45, R81, R84, R85, R86, R93: 100R; R_0805_HandSoldering
R5, R22, R35, R56, R68: 680R; R_0805_HandSoldering
R10, R25, R41, R44, R62: 47k; R_0805_HandSoldering
R29, R71: 20k; R_0805_HandSoldering
R34, R36, R46: 15k; R_0805_HandSoldering
R37: 470R; R_0805_HandSoldering
R49: 4.7k; R_0805_HandSoldering
R53, R77, R107, R108, R109, R110: 47R; R_0805_HandSoldering
R54: 2k2; R_0805_HandSoldering
R59: NOP; R_0805_HandSoldering
R65, R66: 220R; R_0805_HandSoldering
R67, R74: 100k; R_0805_HandSoldering
R69: 360R; R_0805_HandSoldering
R73, R88, R94, R111: 1MEG; R_0805_HandSoldering
R76, R80, R92: 0R; R_0805_HandSoldering
RV1, RV2, RV3, RV4: ALPS_RK09_B10K; Potentiometer_Alps_RK09L_Double_Vertical
SW1, SW2: 2MS1T1B4M7QES; Manufacturer_Part_Number 2MS1T1B4M7QES
U1, U3, U5, U8: OPA1611; SOIC127P600X175-8N
U2: SN74LV541APWR; TSSOP-20_W4.4mm
U4: OPA1652; SOIC127P600X175-8N
U6, U7: AZ1117-ADJ; SOT-223-3_TabPin2
U9: OPA1632DR; SOIC127P600X175-8N
U10: SN74LVC1G86DBVR; TSOT-23-5
X2: 3N12288G33YC; Oscillator_SMD_Abracon_ASE-4Pin_3.2x2.5mm

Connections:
3V3: C2.1, C19.1, C20.1, C31.1, C39.1, C40.1, C41.1, C42.1, C45.1, C51.2, C60.1, D2.1 (K), D8.2 (A), IC1.6 (SELFBOOT), IC1.18 (IOVDD), IC1.34 (PVDD), IC1.36 (AVDD), IC1.39 (PLL_MODE1), IC1.48 (AVDD), IC2.8 (VCC), IC3.8 (VCC), JP4.2, JP5.2, Q6.2 (S), Q8.3 (E), Q12.2 (S), R19.2, R47.2, R49.2, R54.2, R59.2, R60.2, R66.1, R87.2, R89.2, R91.2, SW2.1, U2.20 (VCC), U7.2 (VO), U10.5 (VCC), X2.4 (Vdd)
+1V5: R6.1, R23.1, R38.1, R57.1, U3.3 (+), U3.5 (+), U4.1, U4.2 (-), U8.3 (+), U8.5 (+)
+5V: C37.1, C38.1, R65.1, R74.2, R78.2, U6.2 (VO)
+5VA: R11.2, R26.2, R42.2, R63.2, U4.6 (-), U4.7, U9.2 (VCOM)
+12V: C27.2, C28.1, C36.1, C50.2, C52.2, C53.2, C57.1, C59.2, C61.1, C65.2, C69.1, C70.1, D3.1 (K), D4.2 (A), FL1.3, J16.3, L1.1, R67.1, U1.8 (V+), U3.8 (V+), U4.8 (V+), U5.8 (V+), U6.3 (VI), U7.3 (VI), U8.8 (V+), U9.3 (V+)
/1V5: C43.1, C44.1, IC1.13 (DVDD), IC1.24 (DVDD), Q8.2 (C)
/BCLK_OUT: J3.7, R13.2
/BRD_~RESET: C30.1, D2.2 (A), IC1.5 (_RESET), J7.7, P1.6, Q4.3 (D), Q12.1 (G), R49.1
/DAC0: IC1.46 (VOUT0), R2.1
/DAC1: IC1.45 (VOUT1), R20.1
/DAC2: IC1.44 (VOUT2), R32.1
/DAC3: IC1.43 (VOUT3), R51.1
/LRCK_OUT: J3.9, R14.2
/MCLK: R81.2, U2.3 (A1)
/MCLKI: J11.1, R4.2
/MCLK_OUT: J3.3, R9.2
/MP0: IC1.11 (MP0), R15.2
/MP1: IC1.10 (MP1), R48.1
/MP2: IC1.29 (MP2), J7.4, RV2.5
/MP3: IC1.28 (MP3), J7.3, RV3.5
/MP4: IC1.8 (MP4), R17.2
/MP5: IC1.9 (MP5), R16.2
/MP6: IC1.15 (MP6), R84.1
/MP7: IC1.14 (MP7), R82.1
/MP8: IC1.27 (MP8), J7.2, RV4.5
/MP9: IC1.26 (MP9), J7.5, RV1.5
/MP10: IC1.16 (MP10), R79.1, R86.1
/MP11: IC1.19 (MP11), R85.1
/MUTE: J16.2, Q10.3 (D), R12.2, R27.2, R43.2, R64.2, R83.2
/NEG: C13.2, R46.2
/PCHG: Q4.1 (G), U10.4
/POS: C22.2, R34.2
/RES_MUTE: Q12.3 (D), Q13.1 (G), R94.2
/SCL: IC1.23 (SCL/CCLK), IC2.6 (SCL), IC3.6 (SCL), P1.1, R54.1
/SDA: IC1.22 (SDA/COUT), P1.3, Q9.2 (S), Q11.2 (S), R87.1
/TDM_OUT0: J3.1, R8.2
/WB: IC1.20 (ADDR1/CDATA/WB), R61.2
/WP: IC1.21 (CLATCH/WP), R59.1
/~LINK_ENB: J3.6, R19.1, U2.1 (G1)
BCLK_IN: J3.4, U2.7 (A5)
DATA_IN: J3.10, U2.6 (A4)
Earth: C24.2, FL1.2, J1.1, J9.2 (Ext), J15.1, MH1.1
GND: C2.2, C12.2, C15.2, C16.2, C30.2, C31.2, C36.2, C37.2, C38.2, C39.2, C40.2, C41.2, C42.2, C43.2, C44.2, C45.2, C46.2, C49.2, C51.1, C56.1, C60.2, C61.2, C62.1, C69.2, C70.2, C71.1, D1.1 (K), D5.1 (K), D9.1 (K), FL1.4, IC1.1 (AGND), IC1.7 (ADDR0), IC1.12 (DGND), IC1.25 (DGND), IC1.30 (RSVD), IC1.33 (PGND), IC1.37 (AGND), IC1.38 (PLL_MODE0), IC1.42 (AGND), IC2.1 (A0), IC2.2 (A1), IC2.3 (A2), IC2.4 (VSS), IC3.1 (A0), IC3.2 (A1), IC3.3 (A2), IC3.4 (VSS), J3.5, J7.1, J10.1, JP1.1, P1.10, Q4.2 (S), Q13.2 (S), R55.1, R61.1, R67.2, R68.2, R69.2, R72.1, R76.1, R80.2, R88.1, R90.2, R92.2, R94.1, RV1.4, RV2.4, RV3.4, RV4.4, SW1.MH1, SW2.MH1, U2.10 (GND), U2.19 (G2), U10.3 (GND), X2.2 (GND)
GNDA: C28.2, C50.1, J14.2, JP2.1, R36.2, R92.1, R93.1, U9.6 (V-)
GNDS: C5.2, C6.2, C10.2, C11.2, C17.1, C25.2, C26.2, C27.1, C34.2, C35.2, C47.2, C52.1, C53.1, C57.2, C59.1, C65.1, J12.2, J13.2, J16.1, JP6.2, JP7.2, JP8.2, JP9.2, Q1.3 (C), Q3.3 (C), Q5.3 (C), Q7.3 (C), R10.2, R25.2, R41.2, R62.2, R76.2, R107.2, R108.2, R109.2, R110.2, U1.4 (V-), U3.4 (V-), U4.4 (V-), U5.4 (V-), U8.4 (V-)
LRCK_IN: J3.2, U2.8 (A6)
MCLK_IN: J3.8, U2.9 (A7)
unnamed: C1.1, C4.1, R1.1, U1.1
unnamed: C1.2, R3.1, U1.2 (-)
unnamed: C3.1, R1.2, R2.2, R3.2, R95.1
unnamed: C3.2, R6.2, R7.1, R11.1
unnamed: C4.2, R5.1
unnamed: C5.1, R7.2, U1.3 (+)
unnamed: C6.1, J2.1 (In), J13.3, Q1.2 (E), R5.2, R10.1
unnamed: C7.1, C9.1, R18.1, U1.7
unnamed: C7.2, R21.1, U1.6 (-)
unnamed: C8.1, R18.2, R20.2, R21.2, R96.1
unnamed: C8.2, R23.2, R24.1, R26.1
unnamed: C9.2, R22.1
unnamed: C10.1, R24.2, U1.5 (+)
unnamed: C11.1, J4.1 (In), J13.1, Q3.2 (E), R22.2, R25.1
unnamed: C12.1, IC1.41 (FILTD)
unnamed: C13.1, C64.1, R53.2, R71.1
unnamed: C14.1, R40.2
unnamed: C14.2, J5.1 (In), J14.3, R44.2
unnamed: C15.1, IC1.47 (FILTA)
unnamed: C16.1, IC1.40 (CM), R30.1
unnamed: C17.2, R30.2, U4.3 (+)
unnamed: C18.1, C23.1, R31.1, U5.1
unnamed: C18.2, R33.1, U5.2 (-)
unnamed: C19.2, IC1.35 (PLL_LF), R37.2
unnamed: C20.2, R37.1
unnamed: C21.1, R31.2, R32.2, R33.2, R97.2
unnamed: C21.2, R38.2, R39.1, R42.1
unnamed: C22.1, C64.2, R29.1, R77.1
unnamed: C23.2, R35.1
unnamed: C24.1, FL1.1, J1.2, SW1.2
unnamed: C25.1, R39.2, U5.3 (+)
unnamed: C26.1, J6.1 (In), J12.3, Q5.2 (E), R35.2, R41.1
unnamed: C29.1, C33.1, R50.1, U5.7
unnamed: C29.2, R52.1, U5.6 (-)
unnamed: C32.1, R50.2, R51.2, R52.2, R98.2
unnamed: C32.2, R57.2, R58.1, R63.1
unnamed: C33.2, R56.1
unnamed: C34.1, R58.2, U5.5 (+)
unnamed: C35.1, J8.1 (In), J12.1, Q7.2 (E), R56.2, R62.1
unnamed: C46.1, D4.1 (K), Q10.2 (S), R73.1
unnamed: C47.1, R74.1, U4.5 (+)
unnamed: C48.1, L1.2, R70.2
unnamed: C48.2, C55.2, D7.1 (K), Q2.2 (S), R80.1
unnamed: C49.1, D3.2 (A), Q10.1 (G), Q13.3 (D), R73.2
unnamed: C54.1, Q2.3 (D), R70.1
unnamed: C54.2, D6.1 (K), D7.2 (A)
unnamed: C55.1, D6.2 (A), R75.1
unnamed: C56.2, R75.2, R83.1
unnamed: C58.1, R28.2
unnamed: C58.2, J5.2 (Ext), J14.1, JP2.2, R44.1, R93.2
unnamed: C62.2, D8.1 (K), J7.6, RV1.6, RV2.6, RV3.6, RV4.6
unnamed: C63.1, R95.2, R99.1, U8.7
unnamed: C63.2, R99.2, R102.1, U8.6 (-)
unnamed: C66.1, R97.1, R100.1, U3.7
unnamed: C66.2, R100.2, R104.1, U3.6 (-)
unnamed: C67.1, R96.2, R101.1, U8.1
unnamed: C67.2, R101.2, R105.1, U8.2 (-)
unnamed: C68.1, R98.1, R103.1, U3.1
unnamed: C68.2, R103.2, R106.1, U3.2 (-)
unnamed: C71.2, R111.2, U10.2
unnamed: D1.2 (A), R48.2
unnamed: D5.2 (A), R78.1
unnamed: D9.2 (A), R82.2
unnamed: IC1.2 (ADC0), R34.1
unnamed: IC1.3 (ADC_RES), R36.1
unnamed: IC1.4 (ADC1), R46.1
unnamed: IC1.17 (VDRIVE), Q8.1 (B), R60.1
unnamed: IC1.31 (OSCO), R81.1
unnamed: IC1.32 (MCLKI), J11.2
unnamed: IC2.5 (SDA), Q9.3 (D), R89.1
unnamed: IC2.7 (WP), JP4.1, R55.2
unnamed: IC3.5 (SDA), Q11.3 (D), R91.1
unnamed: IC3.7 (WP), JP5.1, R72.2
unnamed: J2.2 (Ext), JP6.1, R102.2, R107.1
unnamed: J4.2 (Ext), JP7.1, R105.2, R108.1
unnamed: J6.2 (Ext), JP8.1, R104.2, R109.1
unnamed: J8.2 (Ext), JP9.1, R106.2, R110.1
unnamed: J10.2, Q6.1 (G), Q11.1 (G), R90.1, R111.1, SW2.2, U10.1
unnamed: J11.3, R45.1
unnamed: J9.1 (In), J15.2, SW1.1
unnamed: JP1.2, R47.1, X2.1 (EN)
unnamed: Q1.1 (B), R12.1
unnamed: Q2.1 (G), R79.2
unnamed: Q3.1 (B), R27.1
unnamed: Q5.1 (B), R43.1
unnamed: Q6.3 (D), Q9.1 (G), R88.2
unnamed: Q7.1 (B), R64.1
unnamed: R4.1, U2.11 (Y7)
unnamed: R8.1, U2.18 (Y0)
unnamed: R9.1, U2.17 (Y1)
unnamed: R13.1, U2.16 (Y2)
unnamed: R14.1, U2.15 (Y3)
unnamed: R15.1, U2.14 (Y4)
unnamed: R16.1, U2.13 (Y5)
unnamed: R17.1, U2.12 (Y6)
unnamed: R28.1, R29.2, U9.1 (IN-)
unnamed: R40.1, R71.2, U9.8 (IN+)
unnamed: R45.2, X2.3 (OUT)
unnamed: R53.1, U9.5 (OUT-)
unnamed: R65.2, R68.1, U6.1 (ADJ)
unnamed: R66.2, R69.1, U7.1 (ADJ)
unnamed: R77.2, U9.4 (OUT+)
unnamed: R84.2, U2.2 (A0)
unnamed: R85.2, U2.4 (A2)
unnamed: R86.2, U2.5 (A3)

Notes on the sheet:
<=1%
AUTO RESET
RECIVED LRCK
RECIVED BCLK
RECIVED SDATA(TDM)
TDM INTERLINK CONNECTOR
AUX-0
AUX-1
USBi
DC12V
fc = 60kHz (-3dB)
(2.5Vpp)
(2Vrms)
MUTING
INPUT
OUTPUT0
OUTPUT1
OUTPUT2
OUTPUT3
PROGRAM SELECT SW
DAC SIGNAL REFERENCE
SIGNAL BIAS
PROG-B WRITE-PROTECT
OPTIONAL PART FOR TDM-INTERLINK
Note: Use serial EEPROM which has capacity more than or equal 128k bits.
ROM-A
ROM-B
(AUX-ADC1)
(AUX-ADC0)
or 2SD2704KT146
RESERVE MUTE POWER CAP
Use Si Switching Diode for D3 Shotkey is NOT suitable
※ Marked Capacitors are Panasonic “ECHU” Film-Cap or C0G dielectrics Cap for the best Hi-Fi Sound performances.
POWER INDICATOR
CHARGE PUMP
(96kHz)
-11V
+1.5V
3.0V
Maximum AUX-ADC Input Voltage is 3.0V

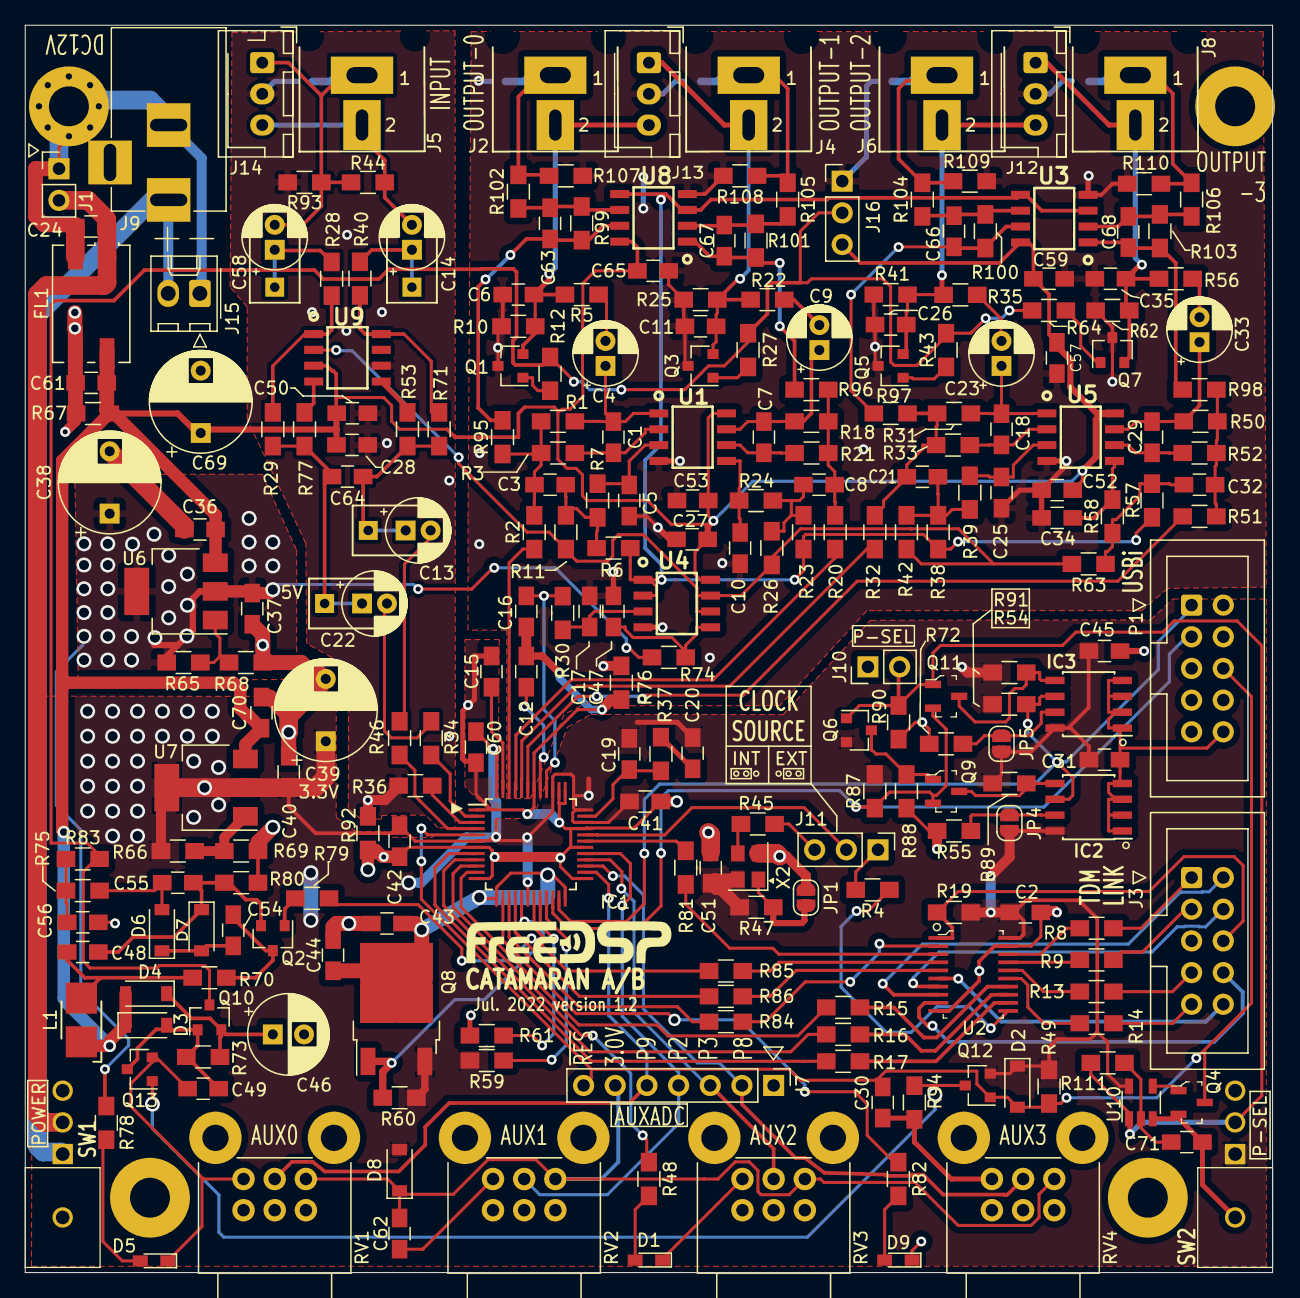
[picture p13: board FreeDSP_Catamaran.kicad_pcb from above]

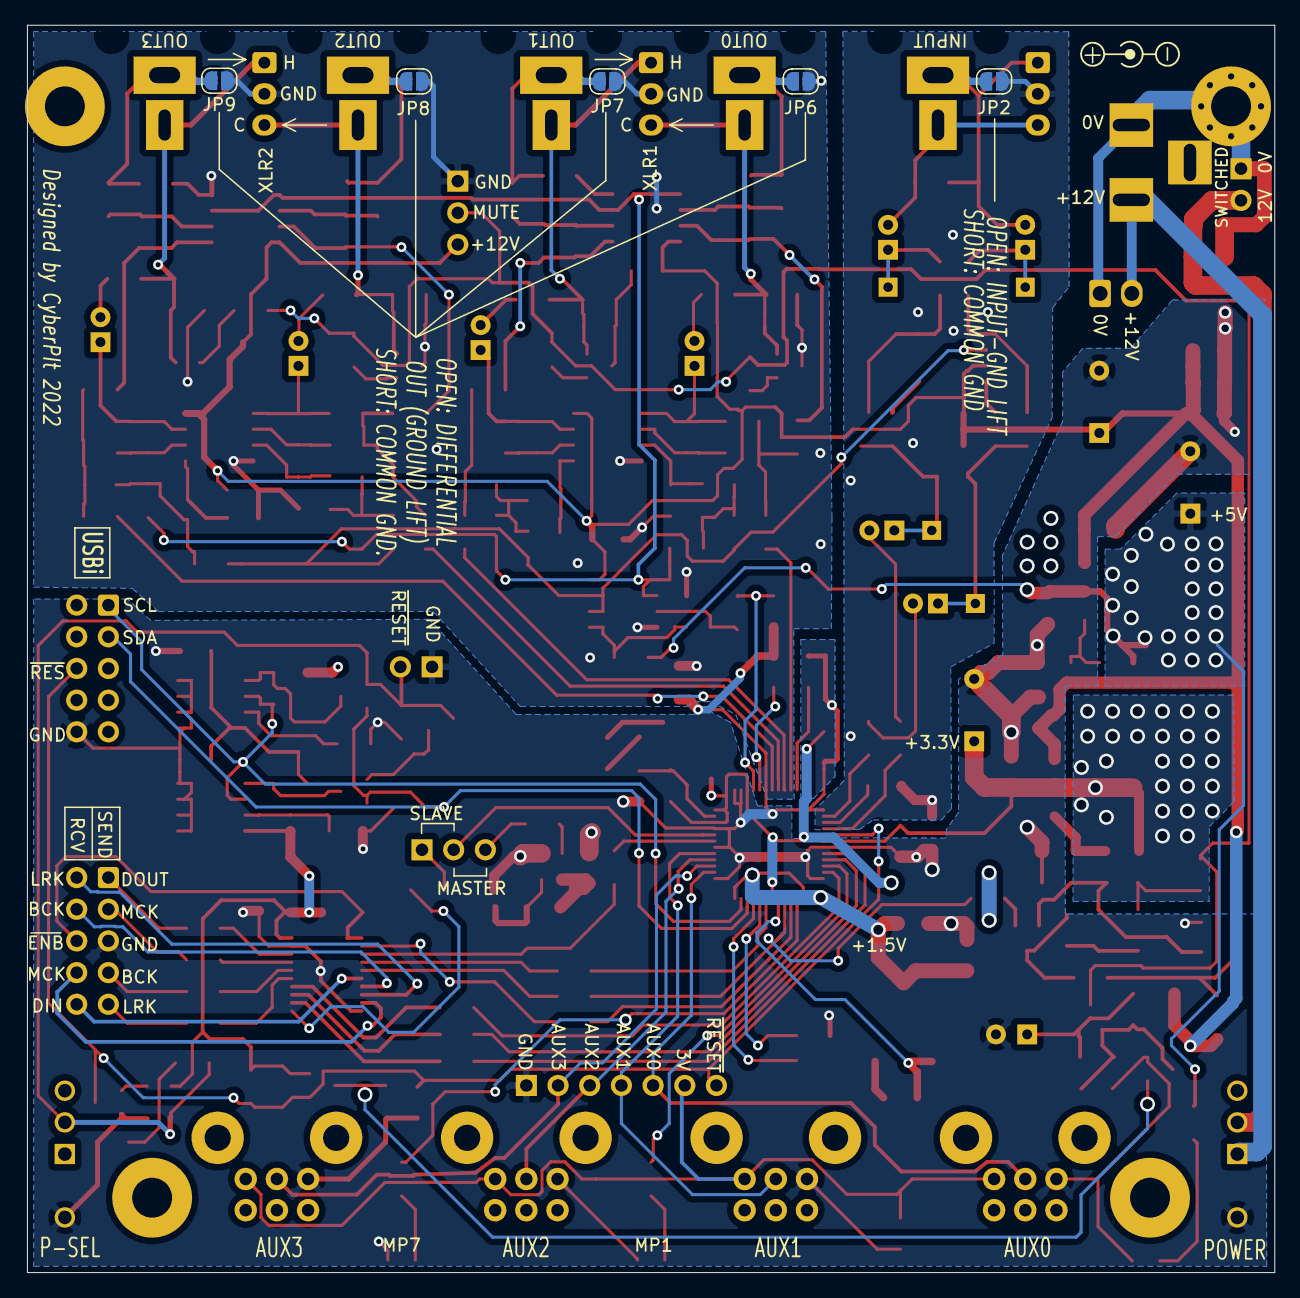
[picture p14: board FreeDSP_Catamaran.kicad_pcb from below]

Board: 2 copper layers, 100.0 x 100.0 mm, 255 parts (5 on the bottom side), 152 nets.

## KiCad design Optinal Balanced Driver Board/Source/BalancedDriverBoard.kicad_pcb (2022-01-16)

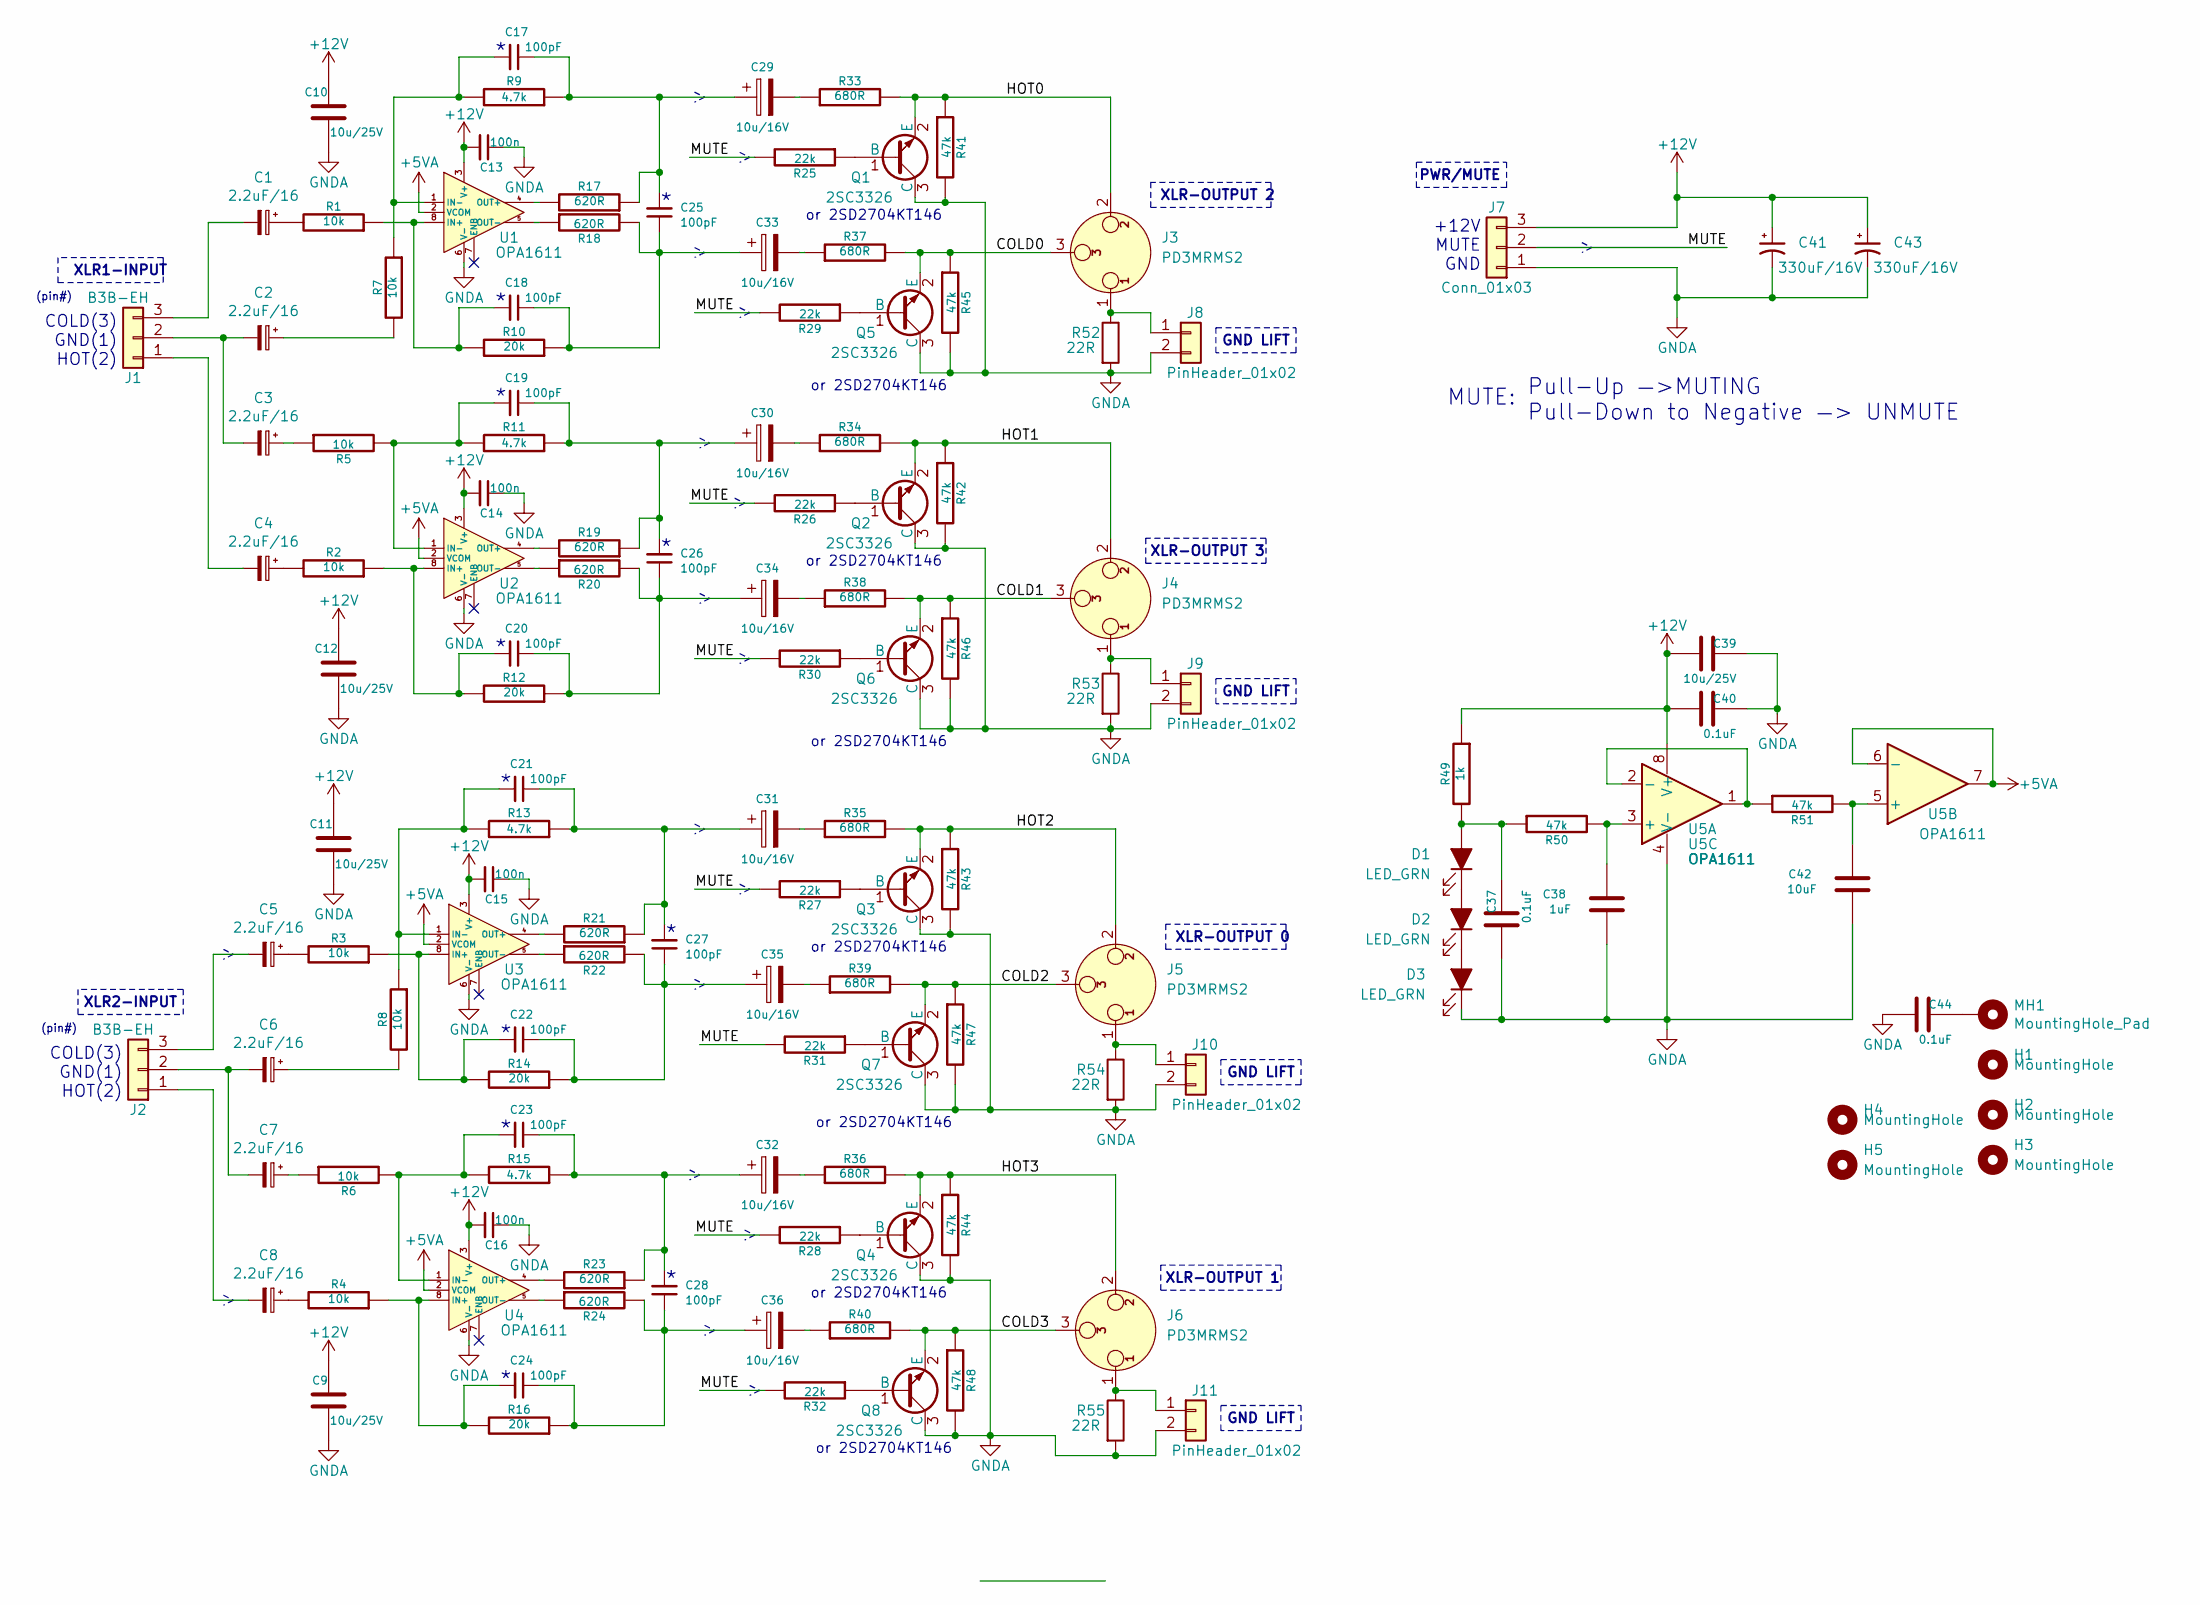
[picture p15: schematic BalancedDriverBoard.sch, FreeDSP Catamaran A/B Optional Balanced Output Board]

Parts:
C1, C2, C3, C4, C5, C6, C7, C8: 2.2uF/16; CP_Combo_D5.0mm_P2-5mm
C9, C10, C11, C12, C39: 10u/25V; C_0805_HandSoldering
C13, C14, C15, C16: 100n; C_0805_HandSoldering
C17, C18, C19, C20, C21, C22, C23, C24, C25, C26, C27, C28: 100pF; C_0805_HandSoldering
C29, C30, C31, C32, C33, C34, C35, C36: 10u/16V; CP_Radial_D5.0mm_P2.00mm
C37, C40, C44: 0.1uF; C_0805_HandSoldering
C38: 1uF; C_0805_HandSoldering
C41, C43: 330uF/16V; CP_Radial_D10.0mm_P2.50mm_P5.00mm
C42: 10uF; C_0805_HandSoldering
D1, D2, D3: LED_GRN; LED_0603_HandSoldering
H1, H2, H3, H4, H5: MountingHole; MountingHole_3.2mm_M3_Pad
J1, J2: B3B-EH; JST_XH_B3B-XH-AM_1x03_P2.50mm_Vertical
J3, J4, J5, J6: PD3MRMS2; SWITCHCRAFT_PD3MRMS2
J7: Conn_01x03; PinHeader_1x03_P2.54mm_Vertical
J8, J9, J10, J11: PinHeader_01x02; PinHeader_1x02_P2.54mm_Vertical
MH1: MountingHole_Pad; MountingHole_3.2mm_M3_Pad_Via
Q1, Q2, Q3, Q4, Q5, Q6, Q7, Q8: 2SC3326; SOT-23
R1, R2, R3, R4, R5, R6, R7, R8: 10k; R_0805_HandSoldering
R9, R11, R13, R15: 4.7k; R_0805_HandSoldering
R10, R12, R14, R16: 20k; R_0805_HandSoldering
R17, R18, R19, R20, R21, R22, R23, R24: 620R; R_0805_HandSoldering
R25, R26, R27, R28, R29, R30, R31, R32: 22k; R_0805_HandSoldering
R33, R34, R35, R36, R37, R38, R39, R40: 680R; R_0805_HandSoldering
R41, R42, R43, R44, R45, R46, R47, R48, R50, R51: 47k; R_0805_HandSoldering
R49: 1k; R_0805_HandSoldering
R52, R53, R54, R55: 22R; R_0805_HandSoldering
U1, U2, U3, U4, U5: OPA1611; SOIC-8_3.9x4.9mm_P1.27mm

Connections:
+5VA: U1.2 (VCOM), U2.2 (VCOM), U3.2 (VCOM), U4.2 (VCOM), U5.6 (-), U5.7
+12V: C9.1, C10.1, C11.1, C12.1, C13.2, C14.2, C15.2, C16.2, C39.1, C40.1, C41.1, C43.1, J7.3, R49.1, U1.3 (V+), U2.3 (V+), U3.3 (V+), U4.3 (V+), U5.8 (V+)
/COLD0: J3.3, Q5.2 (E), R37.2, R45.1
/COLD1: J4.3, Q6.2 (E), R38.2, R46.1
/COLD2: J5.3, Q7.2 (E), R39.2, R47.1
/COLD3: J6.3, Q8.2 (E), R40.2, R48.1
/HOT0: J3.2, Q1.2 (E), R33.2, R41.1
/HOT1: J4.2, Q2.2 (E), R34.2, R42.1
/HOT2: J5.2, Q3.2 (E), R35.2, R43.1
/HOT3: J6.2, Q4.2 (E), R36.2, R44.1
/MUTE: J7.2, R25.2, R26.2, R27.2, R28.2, R29.2, R30.2, R31.2, R32.2
GNDA: C9.2, C10.2, C11.2, C12.2, C13.1, C14.1, C15.1, C16.1, C37.1, C38.2, C39.2, C40.2, C41.2, C42.2, C43.2, C44.1, D3.1 (K), J7.1, J8.2, J9.2, J10.2, J11.2, Q1.3 (C), Q2.3 (C), Q3.3 (C), Q4.3 (C), Q5.3 (C), Q6.3 (C), Q7.3 (C), Q8.3 (C), R41.2, R42.2, R43.2, R44.2, R45.2, R46.2, R47.2, R48.2, R52.2, R53.2, R54.2, R55.2, U1.6 (V-), U2.6 (V-), U3.6 (V-), U4.6 (V-), U5.4 (V-)
unnamed: C1.1, R1.2
unnamed: C1.2, J1.3
unnamed: C2.1, R7.2
unnamed: C2.2, C3.2, J1.2
unnamed: C3.1, R5.1
unnamed: C4.1, R2.2
unnamed: C4.2, J1.1
unnamed: C5.1, R3.2
unnamed: C5.2, J2.3
unnamed: C6.1, R8.2
unnamed: C6.2, C7.2, J2.2
unnamed: C7.1, R6.1
unnamed: C8.1, R4.2
unnamed: C8.2, J2.1
unnamed: C17.1, C25.2, C29.1, R9.1, R17.1
unnamed: C17.2, R7.1, R9.2, U1.1 (IN-)
unnamed: C18.1, C25.1, C33.1, R10.1, R18.2
unnamed: C18.2, R1.1, R10.2, U1.8 (IN+)
unnamed: C19.1, C26.2, C30.1, R11.1, R19.1
unnamed: C19.2, R5.2, R11.2, U2.1 (IN-)
unnamed: C20.1, C26.1, C34.1, R12.1, R20.2
unnamed: C20.2, R2.1, R12.2, U2.8 (IN+)
unnamed: C21.1, C27.2, C31.1, R13.1, R21.1
unnamed: C21.2, R8.1, R13.2, U3.1 (IN-)
unnamed: C22.1, C27.1, C35.1, R14.1, R22.2
unnamed: C22.2, R3.1, R14.2, U3.8 (IN+)
unnamed: C23.1, C28.2, C32.1, R15.1, R23.1
unnamed: C23.2, R6.2, R15.2, U4.1 (IN-)
unnamed: C24.1, C28.1, C36.1, R16.1, R24.2
unnamed: C24.2, R4.1, R16.2, U4.8 (IN+)
unnamed: C29.2, R33.1
unnamed: C30.2, R34.1
unnamed: C31.2, R35.1
unnamed: C32.2, R36.1
unnamed: C33.2, R37.1
unnamed: C34.2, R38.1
unnamed: C35.2, R39.1
unnamed: C36.2, R40.1
unnamed: C37.2, D1.2 (A), R49.2, R50.1
unnamed: C38.1, R50.2, U5.3 (+)
unnamed: C42.1, R51.2, U5.5 (+)
unnamed: C44.2, MH1.1
unnamed: D1.1 (K), D2.2 (A)
unnamed: D2.1 (K), D3.2 (A)
unnamed: J3.1, J8.1, R52.1
unnamed: J4.1, J9.1, R53.1
unnamed: J5.1, J10.1, R54.1
unnamed: J6.1, J11.1, R55.1
unnamed: Q1.1 (B), R25.1
unnamed: Q2.1 (B), R26.1
unnamed: Q3.1 (B), R27.1
unnamed: Q4.1 (B), R28.1
unnamed: Q5.1 (B), R29.1
unnamed: Q6.1 (B), R30.1
unnamed: Q7.1 (B), R31.1
unnamed: Q8.1 (B), R32.1
unnamed: R17.2, U1.4 (OUT+)
unnamed: R18.1, U1.5 (OUT-)
unnamed: R19.2, U2.4 (OUT+)
unnamed: R20.1, U2.5 (OUT-)
unnamed: R21.2, U3.4 (OUT+)
unnamed: R22.1, U3.5 (OUT-)
unnamed: R23.2, U4.4 (OUT+)
unnamed: R24.1, U4.5 (OUT-)
unnamed: R51.1, U5.1, U5.2 (-)

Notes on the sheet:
XLR1-INPUT
(pin#)
COLD(3) GND(1) HOT(2)
PWR/MUTE
or 2SD2704KT146
XLR2-INPUT
+12V MUTE GND
Pull-Up —>MUTING Pull-Down to Negative —> UNMUTE
MUTE:
XLR-OUTPUT 0
XLR-OUTPUT 1
XLR-OUTPUT 2
XLR-OUTPUT 3
GND LIFT

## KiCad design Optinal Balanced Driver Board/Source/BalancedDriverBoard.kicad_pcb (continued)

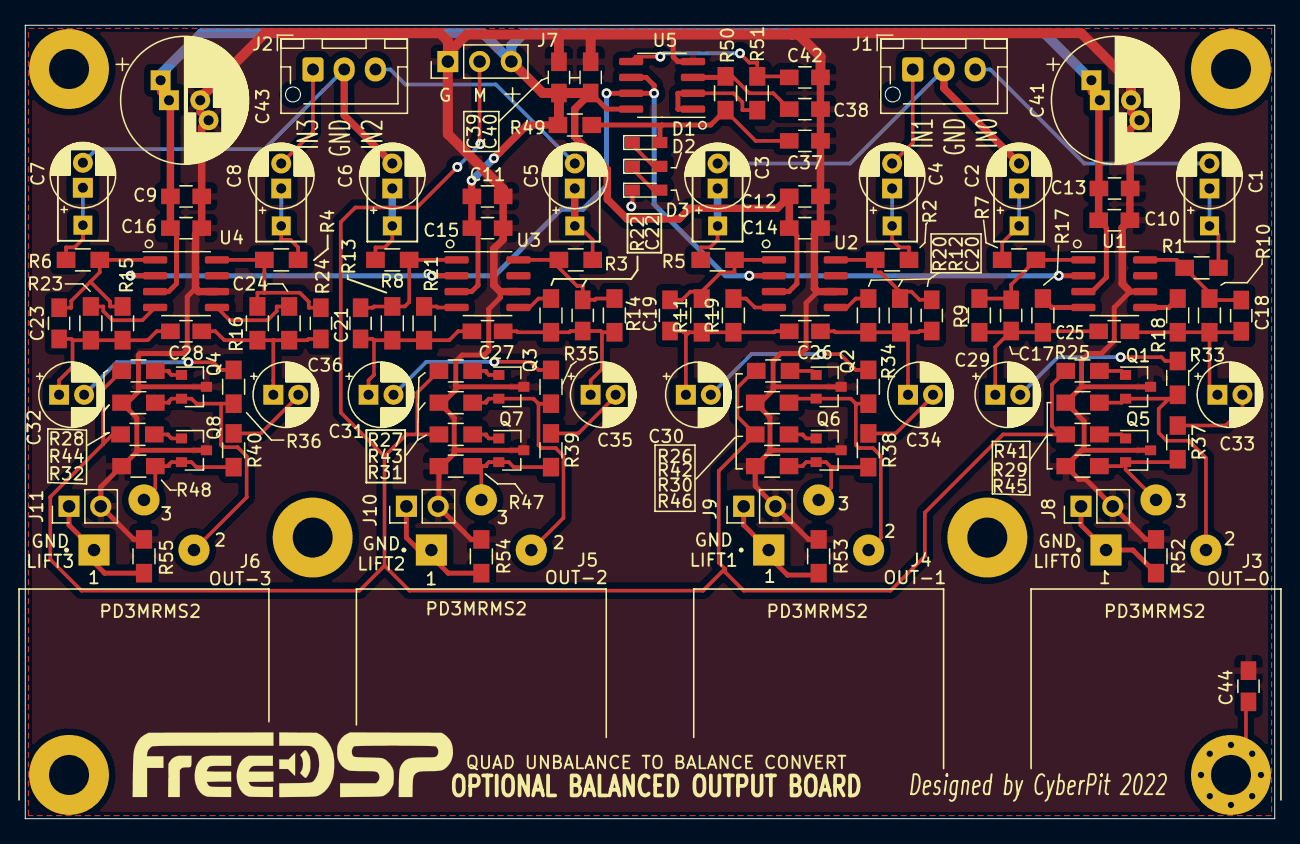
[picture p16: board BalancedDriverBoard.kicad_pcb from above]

Board: 2 copper layers, 100.0 x 63.5 mm, 132 parts (0 on the bottom side), 77 nets.

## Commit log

2022-01-16 FreeDSP Catamaran A/B Main Board
    [FreeDSP_Catamaran-B_Cu.gbl, FreeDSP_Catamaran-B_Mask.gbs, FreeDSP_Catamaran-B_Paste.gbp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]
2022-01-16 Optional XLR Balanced Output Board
    4 unbalanced (Differential) inputs convert to Balanced XLR output.
    This is an optional board. Only for XLR connection.
    FreeDSP Catamaran has Differential Input and Output circuit, so basically this board is not necessary except for connecting XLR Cable.
2022-01-16 FreeDSP Catamaran Main Board
    [FreeDSP_Catamaran.dsn, FreeDSP_Catamaran.kicad_PreRoute20220115_pcb.kicad_pcb, FreeDSP_Catamaran.kicad_pcb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]
2022-01-16 Optional XLR Balaned Output Board
    ki-CAD Design Files
    [BalancedDriverBoard.dsn, BalancedDriverBoard.kicad_pcb, BalancedDriverBoard.sch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]
2022-01-19 JLPCB PCBA order required Files
    [BalancedDriverBoard-B_Cu.gbl, BalancedDriverBoard-B_Mask.gbs, BalancedDriverBoard-B_Paste.gbp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]
2022-01-24 Fixed wrong parts number U1 - U4 as C86715
    [BalancedDriverBoard_BOM1.xlsx]
2022-01-24 FIxed wong parts number U1 - U4 as C86715
    [BalancedDriverBoard_BOM1.xlsx]
2022-01-24 Fixed wrong parts number U1 - U4 as C86715.
    [BalancedDriverBoard_BOM1.xlsx]
2022-01-24 Fixed U1 - U4 parts number as OPA1632.
    [BalancedDriverBoard.sch]
2022-02-12 Update Stacked Board Image drawing
2022-04-29 Version 0.21 JLPCB ordered Files
    [FreeDSP_Catamaran-B_Cu.gbl, FreeDSP_Catamaran-B_Mask.gbs, FreeDSP_Catamaran-B_Paste.gbp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]
2022-04-29 FreeDSP Catamaran A/B version 0.21
    Changed minor silkscreen layouts
    [FreeDSP_Catamaran.kicad_pcb, FreeDSP_Catamaran.sch, FreeDSP_Catamaran_BOM-LIST.xlsx]
2022-04-29 FreeDSP Catamaran A/B Board version 0.21 Diemesions Drawing
2022-04-29 FreeDSP Catamaran A/B DSP Board Mechanical Drawing
2022-04-29 FreeDSP Catamaran A/B 0v21 Schematic
2022-04-29 FreeDSP Catamaran 0v21 Gerber Files
2022-05-17 Evaluated Schematic Crcuit Diagram.
2022-05-17 Evaluated SMT BOM List for JLPCB
    [FreeDSP_Catamaran_BOM1.xlsx]
2022-05-17 SMT Parts Placement File for 0v22 board.
2022-05-17 JLPC oder format Gerber/Drill Data and SMT BOM/CPL
    [FreeDSP_Catamaran-B_Cu.gbl, FreeDSP_Catamaran-B_Mask.gbs, FreeDSP_Catamaran-B_SilkS.gbo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]
2022-05-17 Version1.0 Gerber and SMT Data files for JLPCB
    [FreeDSP_Catamaran_BOM_1v0.xlsx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]
2022-05-17 Version 1.0 Release Ki-CAD Data Files
    [FreeDSP_Catamaran.kicad_pcb, FreeDSP_Catamaran.sch, FreeDSP_Catamaran_BOM-LIST.xlsx]
2022-05-17 Version 1.0 Released Schematic Circuit Diagram
2022-05-17 Version 0.21 Evaluated Stereo Linked Board Photo
2022-05-19 Version 1.0 Board 3D Rendering
2022-05-21 Version 0.21 Parts Mounted Board Photo
2022-05-21 TDM-LINK CABLE Photo
2022-05-29 Version0.21 Board Measured Audio Performances
2022-05-29 version 0.21 Board THD Campion Data (96kHz)
2022-06-13 Some ADC gain resistors are trimmed.
    Resistor value changed. (R29, R34, R36, R46) for gain adjustment.
    The input and output reference level will be 2V RMS.
    [FreeDSP_Catamaran_BOM_1v01.xlsx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]
2022-06-13 Resistors value changed to trim the ADC gain
    Adjust the ADC part gain setting for 2V RMS I/O reference.
2022-06-13 Version 1.01 schematic Circuit Diagram and App
    Input gain adjusted (2V RMS) schematic and 4way channel divider application DSP Schematic.
2022-06-13 4way crossover Application and TDM-LINK function Test File.
    Master -> Set the jumper pin at the J11- "INT" position.
    Slave -> Set the jumper pin at the J11- "EXT" position.
    You can execute 512 steps of DSP codes @96kHz sampling.
2022-07-09 PCBA order fromat files for JLPCB
    Version 1.2 Board Order format Gerber, Drill, Parts, Placement dat files.
    [FreeDSP_Catamaran_BOM_1v2.xlsx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]
2022-07-09 1v2 add auto-reboot feature on PGM-SW transnsition
    The reset switch was removed due to the automatic DSP reboot feature on the transition of the A/B program change.
    [FreeDSP_Catamaran.csv, FreeDSP_Catamaran.kicad_pcb, FreeDSP_Catamaran.sch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]
2022-07-09 Version 1.2 board rederings
    Add a feature of the automatic reboot on the transition of A/B program select switch. The RESET button was removed.
2022-07-09 Version 1.2 added a feature of DSP Auto-Reload
    Added a feature of automatic DSP code reloads on the transition of A/B program select switch.
    The RESET button was removed. (No longer needed)
